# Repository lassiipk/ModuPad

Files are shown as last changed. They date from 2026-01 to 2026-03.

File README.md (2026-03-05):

# MODUPAD
| CAD | *IRL* |
|---|-----|
| ModuPad_FullProduct_Image |  |

**MODUPAD** is a compact **3×3 programmable macropad with a rotary encoder** designed with a **macro‑first, learning‑driven philosophy**.  

This project represents a **from‑scratch learning journey** covering electronics, schematic design, PCB layout, firmware architecture, and documentation—while still resulting in a practical, daily‑use device.

---
<!--
## Device Identity

> **MODUPAD** is a **3×3 macropad + rotary encoder** with layered keymaps, encoder‑driven system control, and an event‑based OLED interface.

---

## Project Goals

- Learn electronics **from near zero** through hands‑on design
- Design a complete keyboard matrix with diodes
- Integrate a microcontroller, rotary encoder, and OLED display
- Build a full PCB in KiCad (schematic → layout → DRC‑clean)
- Design firmware architecture before hardware arrival
- Practice clean documentation and GitHub‑based version control
- Produce a focused, usable macropad without feature creep

This project prioritizes **learning clarity, reasoning, and correctness** over visual complexity.
-->

<!--
## Final Key Features (As Built)

- **3×3 key matrix (9 keys)** dedicated entirely to macros
- **Multiple firmware layers**
  - Layer 0 (Default)
  - Layer 1 (Fn layer)
  - Layer 2 (planned / future)
- **EC11 rotary encoder**
  - Rotation: system volume control
  - Button: OLED mode control
- **0.91” 128×32 I²C OLED**
  - Animation mode
  - Text mode
  - Status mode
  - Full OFF state
- **USB‑C connectivity**
- **Windows‑focused macro design** (Windows 10 & 11)
- **No RGB lighting** (removed during redesign to reduce complexity)

---
<!--
## Encoder Behavior

### Encoder Rotation
- Controls **system volume only**
- Small step size for precision
- Works across **Windows 10 & 11**

### Encoder Button
- **Press:** Cycle OLED animations
- **Fn + Press:** Cycle text/status modes
- **Fn + Hold (3s):** OLED ON / OFF toggle

---

## OLED System

### OLED Modes
1. **Animation Mode**
   - Plays one full animation per `animation_xx.py`
   - Firmware auto‑detects all animation files
   - No hard limit on number of animations
2. **Text Mode**
   - Displays:
     - Creator name
     - Date & time
3. **Status Mode**
   - Displays system states (e.g. mute status)
4. **OFF Mode**
   - OLED fully powered down (true blank state)

OLED behavior is **event‑driven**, not continuously animated.

---

 ## Development Status (Current)

- [x] Concept defined
- [x] Schematic completed
- [x] PCB layout completed
- [x] DRC‑clean board
- [x] Case designed
- [x] Firmware architecture finalized
- [x] Firmware written
- [x] Project uploaded to GitHub
- [ ] Hardware fabrication & assembly
- [ ] Flashing & physical testing
-->

## Firmware Overview

- **Firmware Framework:** KMK (Python‑based)

---

<!-- **Reason for KMK**
  - Python readability
  - Clear firmware structure
  - No dependency on VIA
  - Easier reasoning without hardware in hand

Firmware was designed **before physical assembly**, allowing logic review and iteration in advance.

---

## Why MODUPAD?

**MODUPAD** stands for:
- **MODU** — Modular, adaptable, intentional
- **PAD** — A focused input device

Every decision made in this project supports **clarity, control, and learning**.

---

-->

## Bill of Materials (BOM):
- **Microcontroller:** Seeed Studio XIAO RP2040
- **Keys:** 9 × MX‑style switches
- **Diodes:** 10 1N4148 Diodes (matrix isolation)
- **Encoder:** EC11 rotary encoder with push button
- **Display:** 0.91” I²C OLED (128×32)
- **Connectivity:** USB‑C
- **Case:** Custom‑designed in Fusion 360, 3D‑printed

---

| Schematic | PCB | Case |
|---|-----|---|
| KiCad Schematic | KiCad PCB | Case Screenshot |

---

### Timeline

**Project Started:** 19th December, 2025 | 11:58 PM

**Project Ended:** 2nd January, 2026 | 7:58 PM

**Project Submited:** 2nd January, 2026 | 11:17 PM

**Project 99% Completed:** 12 Febuary | 1:00 PM

**Project 100% Completed:** N/a

---

## License

This project is open‑source and intended for **educational and personal use**.

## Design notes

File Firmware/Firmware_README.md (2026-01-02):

# ModuPad – Firmware Documentation

**Author:** M. Saim Ghazanfar  
**Project:** ModuPad  
**Scope:** Firmware only (KMK-based)

---

## Overview

This document describes the **final firmware design** for the ModuPad project.  
Everything written here is based **strictly on real discussion, iteration, approvals, and decisions** made during the ModuPad firmware design process.

No assumptions.  
No features added afterward.  
No undocumented behavior.

This README is intended for:
- GitHub documentation
- Hack Club project submission
- Future maintenance and expansion
- Learning & documentation purpose

---

## Firmware Goals (Initial Plan)

The original firmware goals were:

- Use **KMK Firmware** (Python-based)
- Avoid VIA to keep things simple and controlled
- Support:
  - 3×3 macro keypad
  - Rotary encoder (rotation + button)
  - OLED display (128×32)
- Work on **Windows 10 and Windows 11**
- Be usable and testable **even before hardware arrives**
- Keep macros **OS-level and reliable**

---

## Key Design Changes & Decisions

### Removed Features
- Addressable LEDs  
  **Reason:**  
  - Took too much PCB space  
  - Increased schematic and firmware complexity  
  - Interfered with encoder placement  

### Changed Approach
- **Discord-specific mute removed**  
  Replaced with **Global Mic Mute**, which works system-wide.

- **Key-combo-heavy macros reduced**  
  Replaced with **Windows `.bat` scripts** for:
  - Stability
  - OS-wide behavior
  - Easy customization without firmware edits

---

## Firmware Stack

- **Firmware:** KMK (Python)
- **Architecture Style:** Modular
- **OS Target:** Windows 10 & Windows 11
- **OLED Resolution:** 128×32
- **Encoder:** Single EC11-style rotary encoder

---

## OLED Animation System

### Animation Files
- Each `animation_xx.py` file represents:
  - **One complete animation**
  - **Not individual frames**
> Example:
>
> OLED_ANIMATIONS/  
> ├── animation_01.py  
> ├── animation_02.py  
> ├── animation_03.py  
> └── animation_04.py

---

### Behavior
- Firmware automatically:
- Detects all animation files
- Loads them dynamically
- Cycles through them using the encoder button
- **No hard limit** on number of animations
- Users can:
- Add or remove animation files
- Without changing firmware logic

---

## Encoder Behavior (Final)

### Rotation
- Controls **system volume only**
- Small step size:
- **2 volume steps per tick**
- Works on:
- Windows 10
- Windows 11

### Encoder Button
| Action | Result |
|---|---|
| Press | Switch OLED animation |
| Fn + Press | Switch OLED text / status mode |
| Fn + Hold (3 seconds) | OLED OFF / ON toggle |

- OLED OFF state is **fully blank**
- No dimming or partial display

---

## Key Layout & Functions

### Physical Layout
- **3×3 matrix**
- Numbered **bottom-left → top-right**

> 7 8 9
>
> 4 5 6
>
> 1 2 3

---

### Layer 0 – Default

| Key | Function |
|---|---|
| 1 | Fn (momentary layer switch) |
| 2 | Screenshot (Win + Fn + Print) |
| 3 | Redo (Ctrl + Shift + Z) |
| 4 | Copy (Ctrl + C) |
| 5 | Paste (Ctrl + V) |
| 6 | Undo (Ctrl + Z) |
| 7 | Open Photoshop (`App1.exe`) |
| 8 | Open Browser |
| 9 | Open File Explorer |

---

### Layer 1 – Fn Held

| Key | Function |
|---|---|
| 1 | --- |
| 2 | Global Mic Mute / Unmute |
| 3 | Window Switch (Alt + Tab) |
| 4 | Task Manager (Ctrl + Shift + Esc) |
| 5 | Toggle Speaker Mute |
| 6 | Open Game (`Game.exe`) |
| 7 | Windows Sleep |
| 8 | Windows Restart |
| 9 | Windows Shutdown |

---

### Key Layout & Functions — Layer 2 (Future Planned Feature)

> **Status:** Planning stage only  
> **Not implemented in current firmware**

### Layer Activation Logic (Proposed)
- **Trigger:** Press the **Fn key 5 times consecutively** (within a short time window).
- **Result:** Activates **Layer 2** (third layer, after Layer 0 and Layer 1).
- **Exit:** Press the **Fn key 5 times consecutively again** to return to **Layer 0 (Default)**.
- This design avoids adding extra physical keys and keeps the hardware simple.

### Intended Purpose of Layer 2
- Reserved for **advanced / power-user macros**.
- Experimental features without disturbing daily-use layers.
- Future expansion space for:
  - App-specific macro sets
  - Debug / development shortcuts
  - OLED debug or diagnostic modes
  - User-customizable workflows

### Design Notes
- Layer 2 is **deliberately not finalized**.
- Key assignments will be defined only after real-world usage of Layer 0 and Layer 1.
- Firmware architecture is designed to allow adding this layer **without breaking existing behavior**.

### Rationale
- Prevents accidental activation.
- Keeps Layer 0 and Layer 1 clean and predictable.
- Provides long-term scalability for ModuPad without hardware redesign.

---

## Windows `.bat` Script Philosophy

### Why `.bat` Files?
- More reliable than key combos
- Work regardless of focused application
- OS-wide behavior
- Easy to edit or replace

### Folder Structure Used by Firmware

> ModuPad/
> ├── Apps_Macros/
> │   ├── App1.exe
> │   └── Game.exe
> │
> ├── Windows_BootOptions/
> │   ├── sleep.bat
> │   ├── restart.bat
> │   └── shutdown.bat
> │
> ├── Utilitits/
> │   ├── Volume_toggle.bat
> │   └── mic_toggle.bat
> │
> ├── OLED_ANIMATIONS/
> │   ├── animation_01.py
> │   ├── animation_02.py
> │   └── animation_03.py
> │
> └── README.md

- Users can replace `.exe` or `.bat` files without touching firmware.

---

## Firmware Architecture Summary

The firmware is written entirely in Python using KMK and is split conceptually into:

- Key matrix handling
- Encoder handling
- OLED manager
- Animation loader
- Macro execution system

The firmware is designed so that:
- It can be written and reviewed **without hardware**
- Behavior is deterministic
- Features are easy to extend later

---

## What Was Learned

- Simplifying early saves time later
- Hardware constraints should guide firmware decisions
- OS-level automation is more reliable than app-specific shortcuts
- OLED usability matters more than flashy visuals
- KMK is powerful even without VIA
- Clear documentation prevents future confusion

---

## Final Notes

This firmware is:

- Purpose-built
- Minimal
- Reliable
- Easy to expand
- Fully aligned with the ModuPad hardware

All firmware decisions documented here are based **entirely on real design discussion and iteration**, not assumptions.

---

**ModuPad Project – Firmware**  
**Author:** Muhammad Saim Ghazanfar

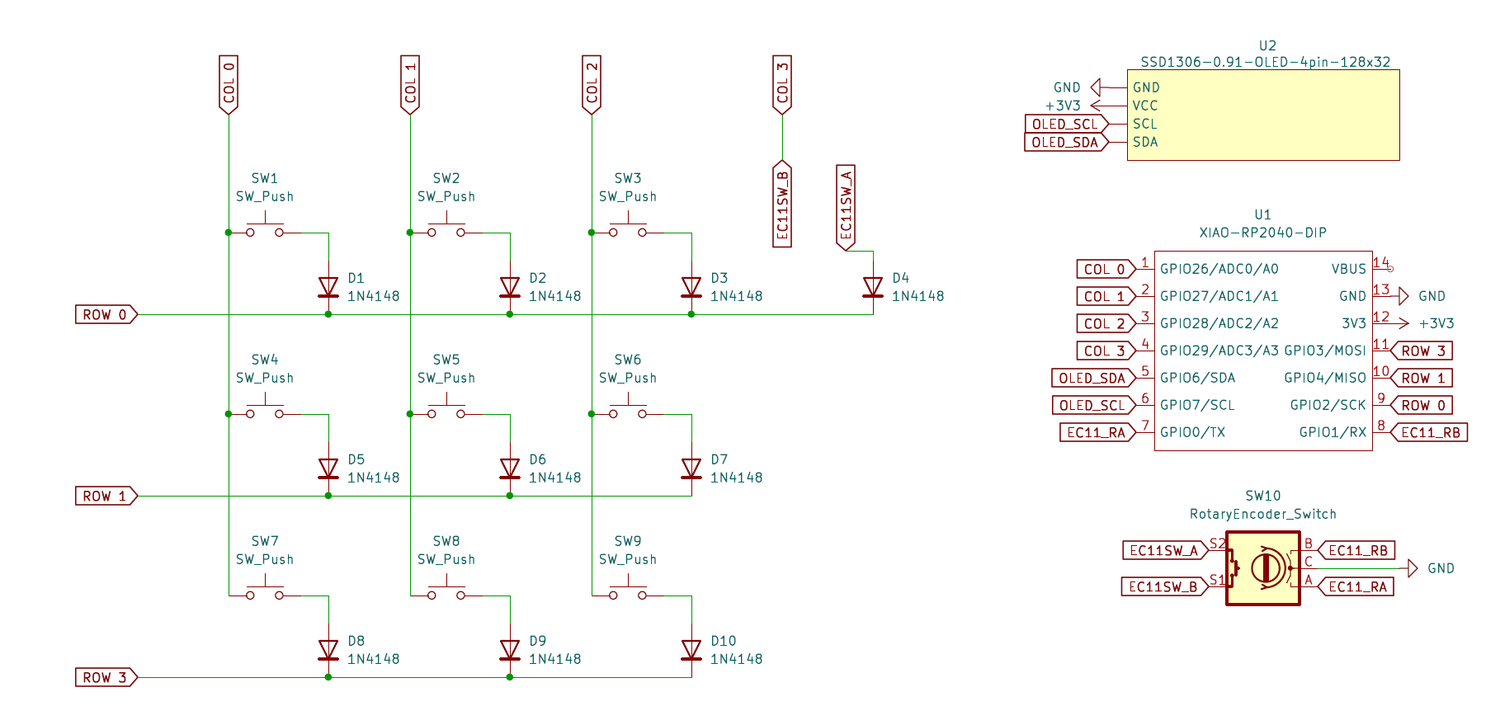
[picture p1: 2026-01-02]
Images/KiCad_Images/01_KiCad_Schematic.png

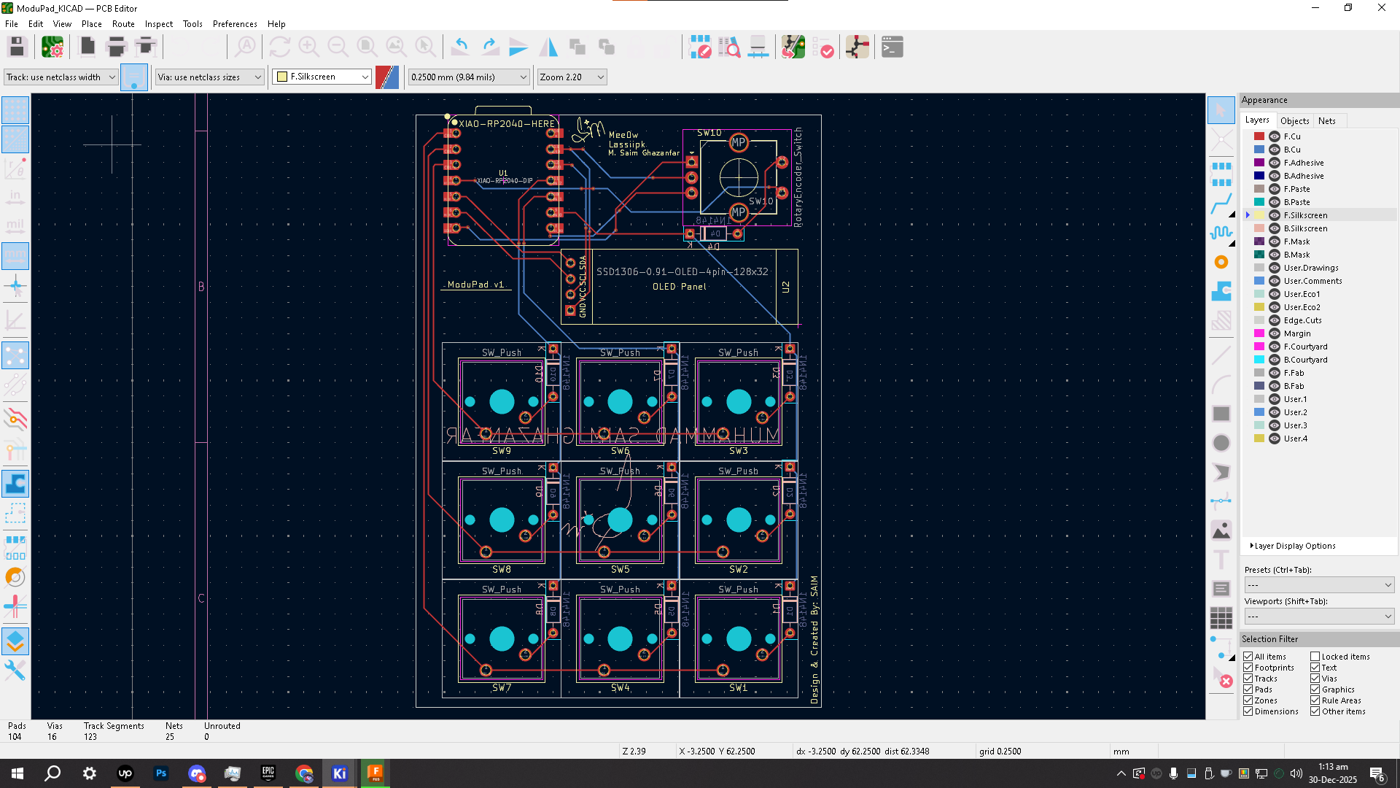
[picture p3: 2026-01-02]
Images/KiCad_Images/02_KiCad_PCB.png

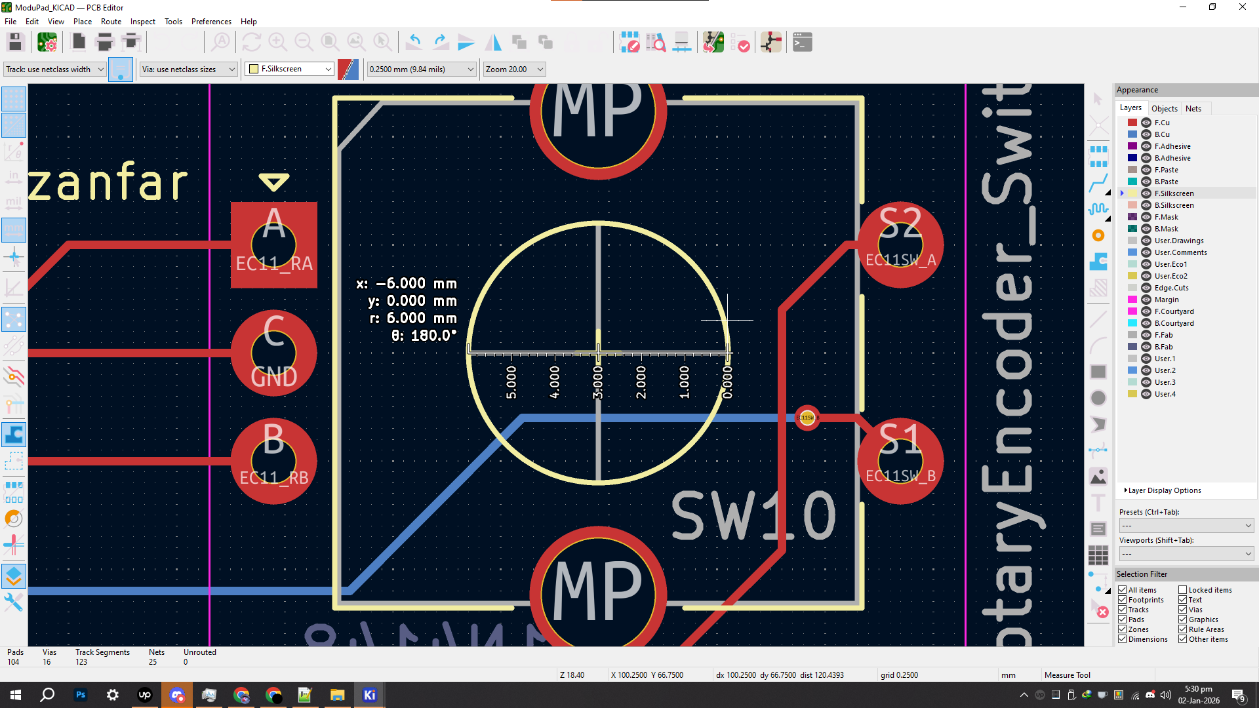
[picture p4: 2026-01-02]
Images/KiCad_Images/07_KiCad_EC11_Encoder-Diameter-Dimentions.png

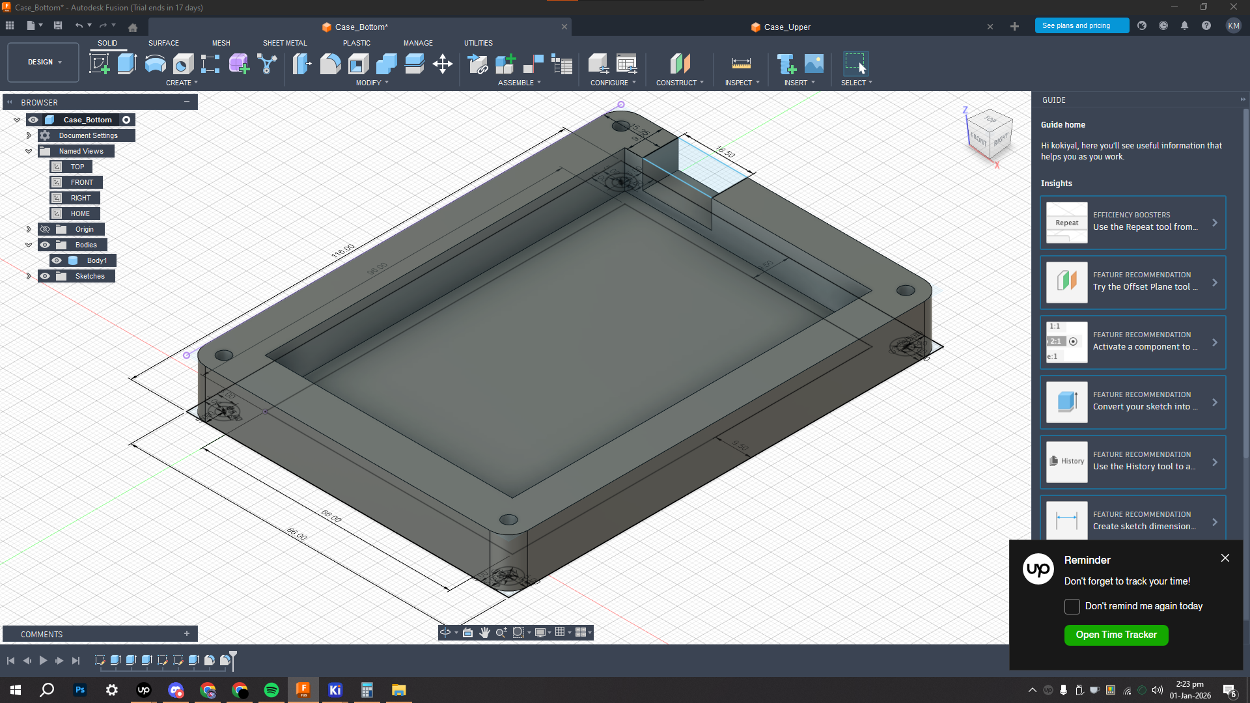
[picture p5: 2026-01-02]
Images/CAD_Images/03_ModuPad_BottomCase_ExtrudeDimentions.png

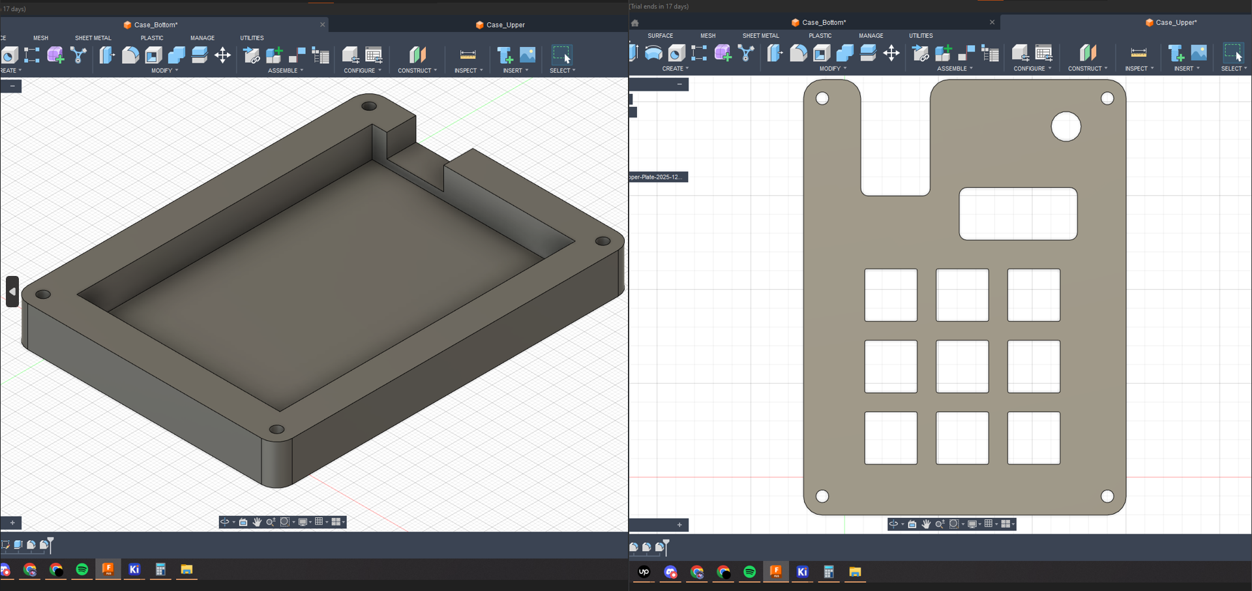
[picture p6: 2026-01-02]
Images/CAD_Images/Screenshot 2026-01-02 214436.png

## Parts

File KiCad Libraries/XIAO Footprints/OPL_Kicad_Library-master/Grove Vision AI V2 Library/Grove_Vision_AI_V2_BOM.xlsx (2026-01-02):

Layer Jump | Number | Name | Specification | Operating Temperature | MPN Code | Quantity | Base | Plug Position | Process
N | 301010000 | SMD RES 0R-5%-1/16W;0402 |  | -55°C to 155°C | RC0402JR-070RL | 3 | 1 | R29,R30,R39 | SMT1
N | 301010004 | SMD RES 10K-5%-1/16W;0402 |  | -55°C to 155°C | RC0402JR-0710KL | 7 | 1 | R5,R7,R8,R23,R24,R31,R38 | SMT1
N | 301010008 | SMD RES 510K-5%-1/16W;0402 |  | -55°C to 155°C | RC0402JR-07510KL | 1 | 1 | R35 | SMT1
N | 301010456 | SMD RES 100K-1%-1/16W;0402 |  | -55°C to 155°C | RC0402FR-07100KL | 7 | 1 | R6,R10,R11,R16,R32,R33,R37 | SMT1
N | 301010495 | SMD RES;5.1K-1%-1/16W;0402 |  | -55°C to 155°C | RC0402FR-075K1L | 3 | 1 | R2,R3,R36 | SMT1
N | 301010746 | SMD RES 2.2K-1%-1/16W;0402 |  | -55°C to 155°C | RC0402FR-072K2L | 10 | 1 | R1,R4,R13,R14,R15,R19,R20,R21,R22,R40 | SMT1
N | 301011331 | SMD RES 22.1K-1%-1/16W;0402 |  | -55°C to 155°C | RC0402FR-0722K1L | 2 | 1 | R26,R34 | SMT1
N | 302010004 | SMD CAP Ceramic 100nF-16V-10%-X7R;0402 |  | -55°C to 125°C | CC0402KRX7R7BB104 | 18 | 1 | C5,C8,C13,C20,C21,C22,C23,C24,C25,C26,C27,C29,C30,C31,C32,C35,C36,C39 | SMT1
N | 302010006 | SMD CAP Ceramic 10nF-50V-10%-X7R;0402 |  | -55°C to 125°C | CC0402KRX7R9BB103 | 1 | 1 | C3 | SMT1
N | 302010049 | SMD CAP Ceramic 12pF-50V-5%-NPO;0402 |  | -55°C to 125°C | CC0402JRNPO9BN120 | 2 | 1 | C14,C15 | SMT1
N | 302010051 | SMD CAP Ceramic 220nF-16V-10%-X7R;0402 |  | -55°C to 125°C | CC0402KRX7R7BB224 | 1 | 1 | C16 | SMT1
N | 302010407 | SMD CAP Ceramic 4.7uF-10V-10%-X5R;0402 |  | -55°C to 85°C | CC0402KRX5R6BB475 | 7 | 1 | C4,C6,C7,C9,C10,C28,C34 | SMT1
N | 302010519 | SMD CAP Ceramic 10uF-10V-20%-X5R;0402 |  | -55°C to 85°C | CC0402MRX5R6BB106 | 2 | 1 | C11,C37 | SMT1
N | 302013249 | SMD CAP Ceramic 1uF-10V-10%-X5R;0402 |  | -55°C to 85°C | CL05A105KP5NNNC | 5 | 1 | C1,C2,C17,C18,C19 | SMT1
N | 303010544 | SMD Inductor 4.7uH-20%-1.1A;0806 |  | -40°C to 105°C | VLS201610HBX-4R7M-1 | 1 | 1 | L1 | SMT1
N | 303011858 | SMD Inductor 470nH-20%-2.6A;0603 |  | -40°C to 125°C | TFM160808ALC-R47MTAA | 2 | 1 | L2,L3 | SMT1
N | 304011053 | SMD Diode Schottky 40V-1A;SOD-323 |  |  | B5819WS SL | 4 | 1 | D1,D2,D3,D4 | SMT1
N | 304090121 | SMD LED Clear-Green;0402 | As posted |  | BL-HGE37A-AV-TRB | 1 | 1 | LED2 | SMT1
N | 304090746 | SMD LED Clear-Yellow;0402 | As posted |  | 16-213/Y2C-AN2Q1B/3T | 1 | 1 | LED1 | SMT1
N | 305030071 | SMD MOSFET N-CH 20V-500mA;SOT-523 |  |  | CJ1012 | 5 | 1 | Q1,Q2,Q3,Q4,Q5 | SMT1
N | 306011444 | SMD Crystal;24MHz-12pF-10ppm-4P-2.0*1.6*0.5mm |  | -40°C to 85°C | Y2400FE001 | 1 | 1 | X1 | SMT1
N | 310011697 | SMD IC MCU;Dual Cortex-M55 Core(Max 400MHz)-With a 400MHz NPU;WLCSP-65 | L5.58*W2.27mm | -40°C to 85°C | HX6538-A01TWA | 1 | 1 | U1 | SMT1
N | 310032794 | SMD IC PMIC;DCDC Buck-ADJ-2.2MHz-4A;DFN1.5×1.5-6 |  | -40°C to 85°C | SY80004DQD | 2 | 1 | U4,U6 | SMT1
N | 310032813 | SMD IC PMIC;LDO-1.8V-300mA;XTDFN-1*1-4L |  | -40°C to 125°C | SGM2036S-1.8XXDH4G/TR | 1 | 1 | U3 | SMT1
N | 310071431 | SMD IC Interface USB to High Speed TTL;QFN16 | USB to High-Speed Serial Port | -40°C to 85°C | CH343P | 1 | 1 | U2 | SMT1
N | 310091468 | SMD IC Memory;128Mbit-1.8V;SOIC-8 |  | -40°C to 85°C | W25Q128JWSIQ | 1 | 1 | U5 | SMT1
N | 311020009 | SMD Top Button 4N;4P-L4.6*W3.2*H2.5mm |  | -20°C to 70°C | SKRPADE010 | 1 | 1 | RST1 | SMT1
N | 311020518 | SMD Top Button 1.57N;4P-L4.6*W3.2*H2.5mm |  | -30°C to 85°C | SKRPABE010 | 1 | 1 | BOOT1 | SMT1
N | 312030502 | SMD DIGITAL MIC OMNI -26dBFS;OCLGA-4:3.5*2.65*0.94mm |  | -40˚C to 100˚C | MSM261D3526H1CPM | 1 | 1 | MIC1 | SMT1
N | 319015667 | PCB;Grove - Vision AI Module V2 -蓝油白字-4层 | 20*40*1.6mm-ENIG-FR4;Steel mesh code；404012305 |  |  | 1 | 1 |  | SMT1
N | 320011358 | SMD USB TYPE C-W/P;12+4P-8.94*7.35*3.26mm |  | -30°C to 85°C | USB-31C-F-16P-L7.35 | 1 | 1 | J1 | SMT1
N | 320031231 | DIP Black Female Header VERT;1*7P-2.54-5.0mm |  | -40℃ to 105℃ |  | 2 | 1 | P8,P9 | Unit
N | 320060904 | SMD FPC CONN Bottom Contact;15P-1.0mm;L19.9*W6.76*H2.0mm |  | -30°C to 85°C | ST-FPC-W102015-D | 1 | 1 | J2 | SMT1
N | 320090535 | SMD uSD Card Holder;9+4P-L11.25*W6.96*H1.42mm |  | -25°C to 70°C | ST-TF-MR267 | 1 | 1 | J5 | SMT1
N | 320110032 | SMD Grove Female Header-Beige;4P-2.0-90D | 2.0-4PHorizontal Mount with Locking Socket |  | PHS-4A horizontal mount | 1 | 1 | J3 | SMT1

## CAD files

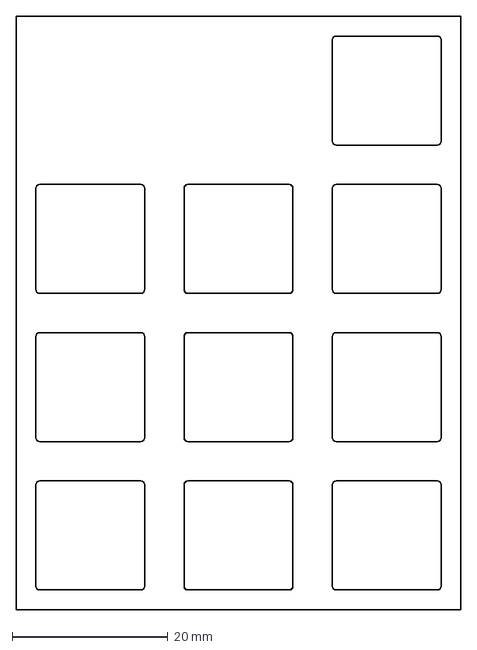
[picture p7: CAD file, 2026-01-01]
CAD/DXF_Files/ModuPad_Upper-Plate-2025-12-28T20_50_54.815Z.dxf
57.1 x 76.2 mm

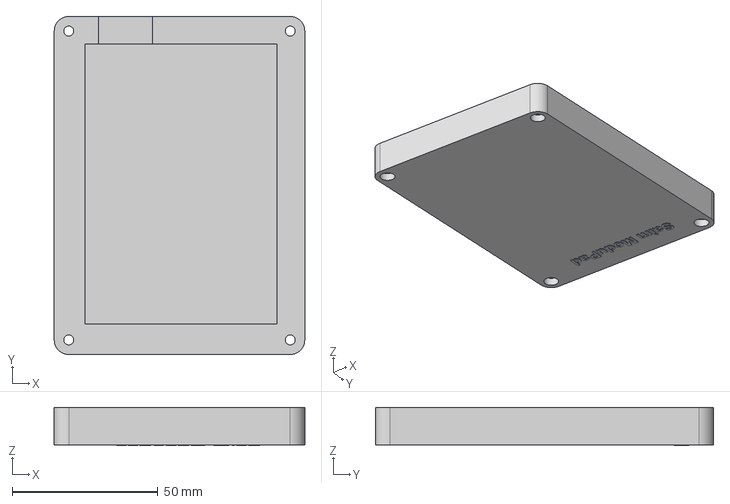
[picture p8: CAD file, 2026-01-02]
CAD/STEP_Files/Case_Bottom.step
86.0 x 116.0 x 13.2 mm

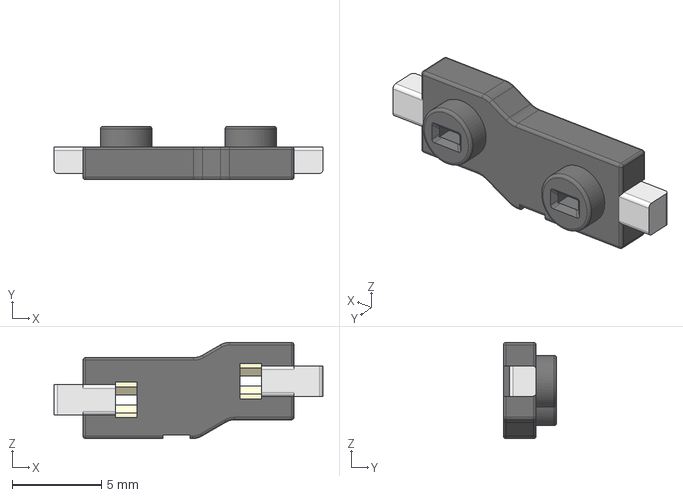
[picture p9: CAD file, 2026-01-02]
KiCad Libraries/Keyswitch_Footprints/MX_V2-main/3D/Gateron-KS33-Socket.step
15.1 x 3.00 x 5.40 mm

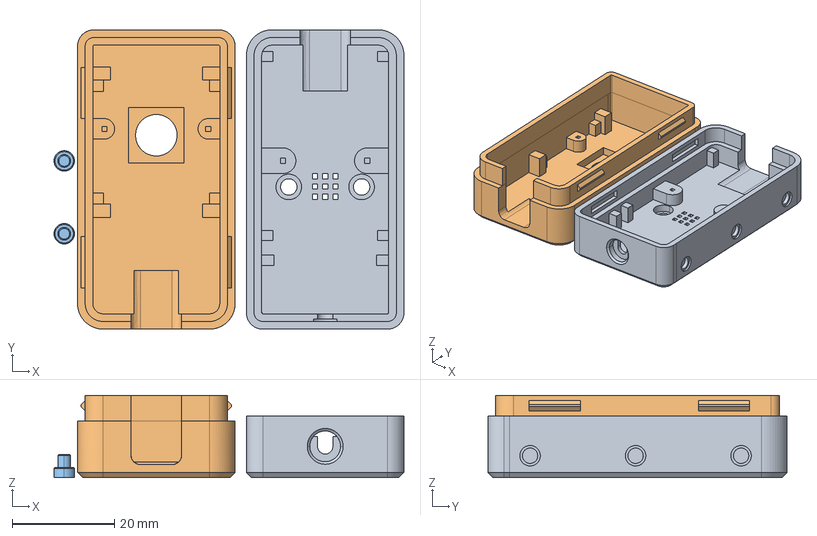
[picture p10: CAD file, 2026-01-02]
KiCad Libraries/XIAO Footprints/OPL_Kicad_Library-master/Grove Vision AI V2 Library/himax.stp
68.4 x 58.5 x 16.1 mm

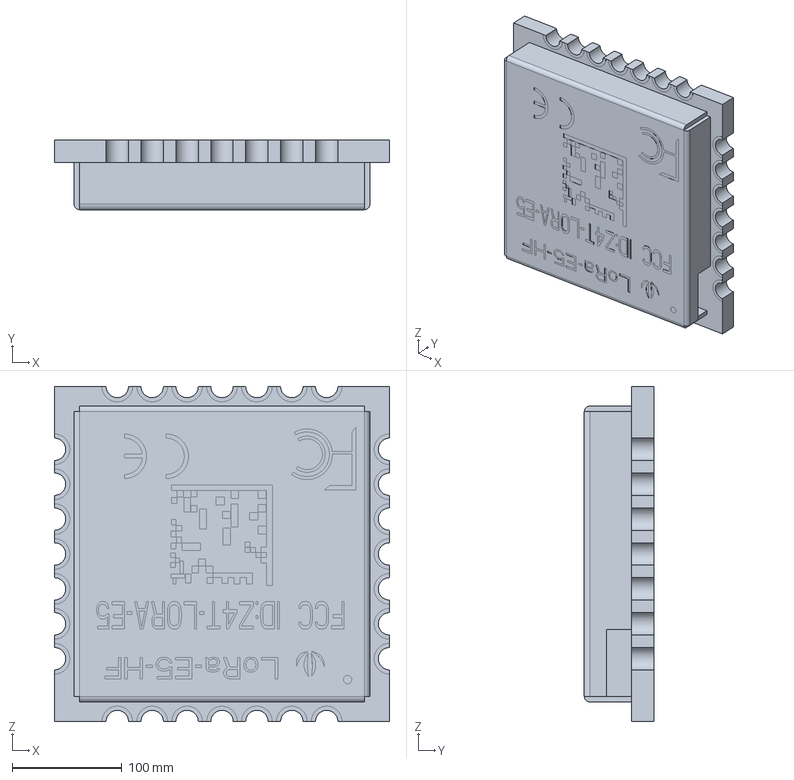
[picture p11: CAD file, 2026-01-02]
KiCad Libraries/XIAO Footprints/OPL_Kicad_Library-master/Seeed Studio Wio Series/Wio-E5-LE/LoRa-E5-LE-HF_3D_File.stp
304.8 x 63.8 x 304.8 mm

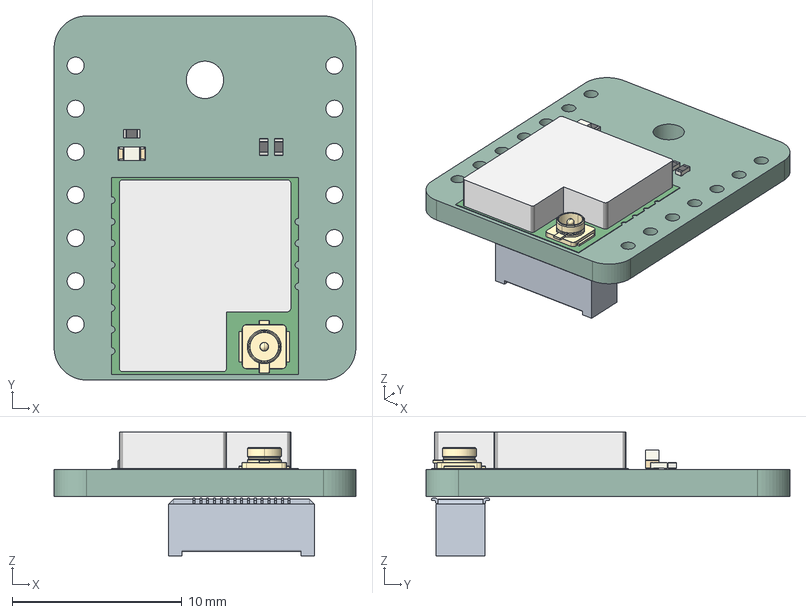
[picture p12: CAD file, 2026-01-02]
KiCad Libraries/XIAO Footprints/OPL_Kicad_Library-master/Seeed Studio Wio Series/Wio-SX1262/Wio-SX1262_for_XIAO_3D_file.step
17.8 x 21.4 x 7.30 mm
R_0402_1005Metric x 3
LED_0603_1608Metric
PCB
BF04-30pin-35H
Wio-SX1262 for XIAO V1.0_PCB

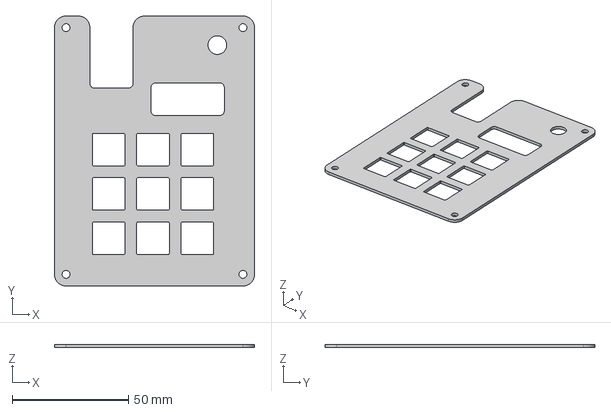
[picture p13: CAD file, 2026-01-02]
CAD/STEP_Files/Case_Upper.step
86.0 x 116.0 x 1.50 mm

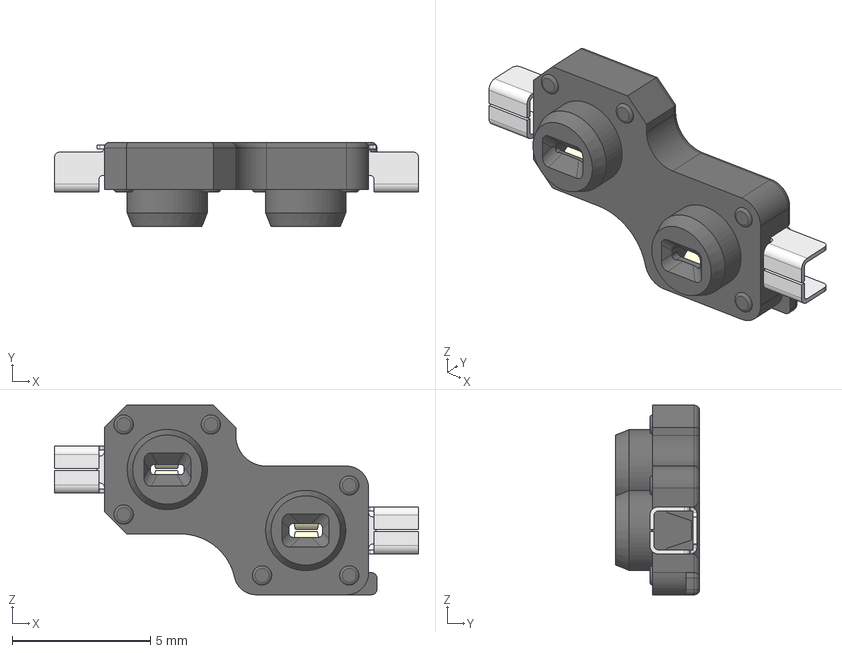
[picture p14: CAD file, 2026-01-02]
KiCad Libraries/Keyswitch_Footprints/MX_V2-main/3D/Kailh-Choc-Socket-CPG135001S30.step
13.1 x 3.05 x 6.85 mm
Insert 2
Insert 1

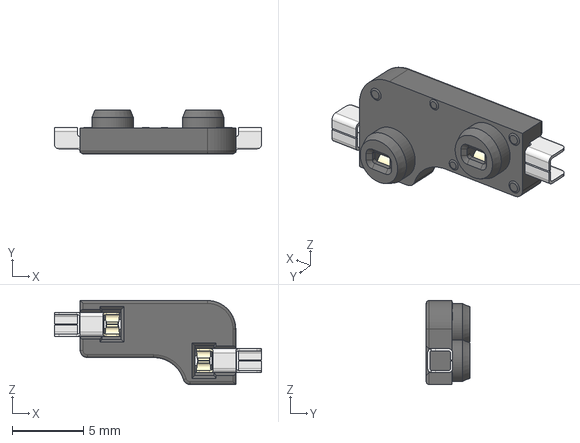
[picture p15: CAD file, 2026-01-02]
KiCad Libraries/Keyswitch_Footprints/MX_V2-main/3D/MX-Hotswap-Socket.step
14.5 x 3.05 x 5.89 mm

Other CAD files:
CAD/F3D_Files/Case_Bottom.f3d
CAD/F3D_Files/Case_Upper.f3d
CAD/STL_Files/Case_Bottom.stl
CAD/STL_Files/Case_Upper.stl
KiCad Libraries/XIAO Footprints/OPL_Kicad_Library-master/Grove Vision AI V2 Library/himax.3mf

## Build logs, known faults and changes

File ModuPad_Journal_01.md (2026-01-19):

## Update

### 🔧 Soldering Iron
I ordered the soldering iron through my **18$ Grant** on **5 January 2026**.  
It was delivered on **17 January 2026** and received by me on **19 January 2026**.  
Total time in transit was **14 days**.

### 🧩 PCB & Components
The **PCB order has been placed** and is currently on its way.  
I also received an **email confirmation** stating that all required pad components have been shipped.

### 🖨️ 3D-Printed Case
The 3D-printed case was delayed due to issues with the grant during the purchasing phase.  
These issues are now resolved, and **the print payment has been confirmed and completed**.  
The order is ready to proceed.

### ✅ Status
The project is now clear of purchasing issues, and I am excited to complete it as soon as the remaining parts arrive.

---

### 📸 Images
| Image 1 | Image 2 | Image 3 |
|---|---|---|
| IMG_20260119_162121_Censored |  |  |

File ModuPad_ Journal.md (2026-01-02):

# Creating a HackPad (Macropad) from Scratch  
**A Zero‑to‑One Electronics Learning Project**

---

## 1. Project Context

### Objective and Scope
This project documents the complete journey of designing and building a custom **HackPad (macropad)** from scratch, starting with near‑zero electronics and PCB design knowledge and progressing through schematic design, PCB layout, enclosure design, and firmware development.

The scope explicitly includes:
- Electronics learning through practice (schematic → PCB → firmware)
- Iterative redesigns and corrections
- Firmware architecture using KMK
- Reflection on learning efficiency and mistakes

Manufacturing and physical assembly are out of scope for this report.

### Initial Skill Level and Constraints
- Near‑zero prior experience in:
  - Electronics fundamentals
  - PCB design tools (KiCad)
  - Keyboard firmware
- Constraints:
  - No immediate access to hardware during firmware development
  - Learning occurred primarily through iterative problem‑solving and feedback
  - Public documentation intended for GitHub

### Motivation
- Learn electronics by building a real, functional device
- Replace theory‑only learning with applied design
- Create a personal reference for future projects

---

## 2. Planning Phase

### Explicit Plans
- Design a custom macropad with:
  - 3×3 key matrix
  - Rotary encoder
  - OLED display
  - Custom firmware
- Use KiCad for schematic and PCB
- Use KMK firmware (Python‑based)

### Implicit Assumptions
- Editing symbols and footprints would be straightforward
- Firmware complexity would be manageable late in the project
- Features could be added incrementally without architectural impact

### Missing or Flawed Planning
- Underestimated:
  - Footprint management complexity
  - ERC/DRC iteration time
  - Firmware architecture planning
- No early firmware‑hardware co‑design planning

---

## 3. Execution & Accomplishments

### Completed
- Fully wired schematic with zero ERC errors
- PCB layout with resolved DRC issues
- Case design in Fusion 360
- Complete firmware architecture and keymap
- Project uploaded to GitHub

### Assumed but Initially Incomplete
- Correct footprint libraries
- Encoder/OLED integration logic
- Clean firmware structure

### Partial Progress Areas
- Advanced firmware layers (future‑planned, not implemented)
- Hardware validation pending part delivery

---

## 4. Redesigns, Revisions, and Direction Changes

### Major Changes
- Removal of LEDs due to space and complexity
- Redesign of key matrix and encoder placement
- Shift from application‑specific shortcuts to OS‑level scripts
- Separation of mic mute and volume mute logic

### Why Changes Occurred
- Physical constraints
- Firmware reliability concerns
- Over‑engineering early features

### Impact
- Simplified hardware
- More reliable firmware
- Improved learning clarity

---

## 5. Hard Parts & Friction Points

### Technical
- KiCad symbol vs footprint mismatches
- ERC and DRC error interpretation
- OLED pin duplication issues
- Encoder footprint mismatches

### Cognitive
- Overconfidence in early decisions
- Difficulty forming correct mental models
- Feature creep before core stability

### Communication
- Misinterpretation of feature intent (e.g., audio output vs mute)

---

## 6. Timeline, Progress Tracking & Traceability

- All timestamps originate from chat messages
- Timezone reference: **Pakistan Standard Time (Islamabad)**

### Limitations
- Some early conceptual shifts span multiple messages
- No explicit “milestone completion” timestamps were recorded
- Gaps exist between understanding → decision → action

These gaps are explicitly acknowledged as a learning limitation.

---

## 7. Learning Analysis

### Explicit Lessons
- Firmware must follow hardware reality
- Simpler designs accelerate learning
- ERC/DRC are learning tools, not obstacles

### Implicit Learning
- Importance of iteration
- Value of removing features
- Documentation clarifies thinking

### Missed Opportunities
- Earlier firmware prototyping
- Earlier external reference checking

---

## 8. Learning Mapped to Electronics Fundamentals

- **MCU Basics:** GPIO mapping, power pins, VBUS handling
- **Switch Matrices:** Rows, columns, diodes, ghosting prevention
- **Power:** 3.3 V rails, grounding discipline
- **Firmware:** Matrix scanning, layers, event handling

---

## 9. Mistake Classification

### Knowledge Gaps
- Footprint libraries
- OLED module variations

### Execution Errors
- Missing footprints
- Misassigned nets

### Reasoning Failures
- Assuming shortcuts equal robustness
- Adding features before stabilizing architecture

---

## 10. Confidence vs Actual Understanding

- **Overconfidence:** Early schematic confidence before ERC mastery
- **Underconfidence:** Firmware hesitation despite adequate Python skill
- Impact: Rework and delays

---

## 11. Assumptions, Errors, and Reasoning Failures

- Assuming editing symbols was unavoidable
- Assuming app‑specific shortcuts were reliable
- Underestimating firmware architecture importance

---

## 12. External Research Gaps

- Limited early reading on keyboard firmware structure
- Minimal upfront review of OLED integration examples

Consequences:
- Relearning concepts mid‑project

---

## 13. Cause–Effect Evaluation

### Accelerators
- Removing LEDs
- Switching to OS‑level scripts
- Clear feature approval checkpoints

### Slowdowns
- Feature creep
- Late architecture decisions

---

## 14. Next Steps After Learning

- Hardware assembly and testing
- Firmware refinement based on real‑world use
- Power and EMI considerations

---

## 15. Concept Glossary

- **ERC:** Electrical Rules Check
- **DRC:** Design Rules Check
- **KMK:** Python‑based keyboard firmware
- **Matrix Scanning:** Reading keys via rows and columns
- **Footprint:** Physical PCB representation of a component

---

## 16. Future Prompt Generation

- “Explain matrix scanning at the electrical level”
- “Compare KMK vs QMK architecture”
- “Best practices for small OLED firmware design”

---

## 17. Improvement Recommendations

- Plan firmware earlier
- Freeze hardware before feature expansion
- Document assumptions explicitly

---

## 18. Post‑Completion Review

In hindsight:
- Feature reduction improved learning
- Documentation should start earlier
- Architecture decisions matter more than polish

---

## 19. Improved Version Proposal (v2)

### Hardware
- More keys
- Dedicated power filtering
- Optional expansion headers

### Firmware
- Multi‑layer state machine
- Configurable animation loader
- Optional host communication

### Learning Process
- Research → design → implement → reflect loop
- Earlier validation checkpoints

---

**Status:**  
Project completed up to firmware stage.  
Repository publicly available.  
This document reflects real decisions, real mistakes, and real learning—without fabrication.

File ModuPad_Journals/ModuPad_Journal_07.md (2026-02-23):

**9 Feb 2026**

After the previous day’s failures, I shifted my focus to testing the key switches since the encoder functionality was still not behaving as intended.

After a lot of struggle, I finally managed to make one key respond as an input device — just like a normal keyboard key. I had to experiment with pin assignments to figure out the correct configuration, but I eventually got it working.

Then I managed to get three keys in a column working simultaneously.

My encoder button was part of the matrix, so I got that working too.

However, no matter what I tried, only four keys were functioning. The rest were completely unresponsive. I couldn’t figure out why.

---

> Journal Entry Written: 11 Feb 2026 | 12:50 - AM

---



---

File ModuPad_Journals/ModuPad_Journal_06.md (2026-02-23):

### ModuPad – CASE

---

### Images
| Image 1 | Image 2 | Image 3 |
|---|---|---|
| IMG_20260208_181629_Censored |  | IMG_20260208_181614_Censored |

---

My pad case was delivered on 8th Feb. The print quality was top-notch. I even complimented the person who printed it — the craftsmanship was impressive.

But there was bad news.

There were measurement errors and branding alignment issues. The encoder and display cutouts were slightly off relative to the PCB. The key switches and MCU placements were accurate, but the encoder and display alignment were wrong.

My father and I analyzed the issue and concluded that we needed to manually cut part of the upper plate to allow the encoder and display to fit correctly. The bottom case had no issues — the PCB fit perfectly there.

We also realized something critical: we had to desolder the key switches. The correct assembly order required placing the upper plate first and then soldering the switches through it.

So we unsoldered the switches, modified (cut) the upper plate to properly align with the PCB, then reassembled everything and tightened the screws.

Honestly, it looked great after the modification. Really satisfying to see it come together.

---

> Journal Entry Written: 11 Feb 2026 | 12:50 - AM

---

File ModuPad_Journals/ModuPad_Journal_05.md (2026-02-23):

**8 Feb 2026**

I continued testing the encoder to confirm everything was stable. After that, I moved on to implementing its intended function — controlling Windows volume.

I tried very hard but was unsuccessful.

After multiple failures, I shifted my focus to QMK-based firmware. Again, I faced difficulties. It was written in C, and everything felt very complicated. The reason I originally chose KMK over QMK was exactly this — QMK is very advanced and powerful, probably best suited for my ModuPad, but KMK is Python-based and easier to understand.

One big advantage of KMK was flashing. First, I installed CircuitPython onto the MCU. After that, the board appeared as a USB drive (CIRCUITPY / Seeed-XIAO-RP2040). Making changes was simple — I only had to modify `code.py` directly on the drive.

Despite that convenience, I struggled a lot with functionality. After many failed attempts, I quit for the day and went to sleep.

---

> Journal Entry Written: 11 Feb 2026 | 12:50 - AM

---

> The Image provided is of Compiling statusof  my OMK based Firmware.
>
> Ignore the mess around my Desk and LCD, its always like this!

733baa89-5d99-4c6c-8100-c8d66cede92e

---

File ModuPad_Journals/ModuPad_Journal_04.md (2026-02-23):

### Re-Writing Firmware

**7 Feb 2026**

After discovering that the firmware was not working for my Seeed XIAO RP2040, I had to dig deep into KMK firmware writing. I decided to create a simple test program to verify whether my pad was functioning properly — checking for wiring errors and confirming that everything was working as planned.

I managed to test my encoder by reading TRUE/FALSE signals that changed based on its rotation direction. That made it clear that the encoder hardware was working fine and should perform correctly in KMK.

No hardware issues.

---

> Journal Entry Written: 11 Feb 2026 | 12:50 - AM

---



---

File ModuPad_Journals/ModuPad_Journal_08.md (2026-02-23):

**9 Feb 2026 | 11:00 PM – 11:20 PM**

With an exhausted mind, I shifted my focus again — this time to the OLED screen.

I didn’t even know if it worked. Was there an electrical issue? A wiring mistake? Something else I overlooked?

It was confusing and frustrating. I felt like I wasn’t making progress.

Then I remembered that I had previously seen other HackPads in Hack Club repositories. I went back and searched through those projects. I found example code related to OLED displays and modified it to match my project.

It still didn’t work.

I used ChatGPT to debug the error, and I discovered the actual problem: I didn’t have the required libraries inside my CircuitPython `lib` folder.

After adding the correct libraries, the OLED finally worked.

It was extremely satisfying to see text displayed on the screen for the first time.

I experimented a bit more with the code and managed to display some cool custom text.

That moment felt like real progress.

Screenshot (510)

---

> Journal Entry Written: 11 Feb 2026 | 12:50 - AM

---

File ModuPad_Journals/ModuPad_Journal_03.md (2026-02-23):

### Components!

Receiving the components was a great experience — completely different from the PCB situation. They delivered everything right to my doorstep, which made it even better. I was genuinely excited. I wanted to solder them immediately.

When I opened the package, I was impressed. All the parts were very small, but very satisfying to look at and place on the PCB. Aligning them felt precise and accurate — they fit perfectly.

---

**Parcel received:** 5th Feb | 3:00 PM

After receiving it, I carefully examined all the parts. I checked everything thoroughly. I was tempted to start soldering right away, but I stopped myself because I needed to prepare properly before soldering onto the board.

At 11:00 PM, I finally started the soldering process.

Before soldering, I inspected everything again. Since I was about to solder all the components, I didn’t want to make a mistake. I first checked their placement on the PCB and only then began soldering.

I started with the MCU. It was very difficult. It was my first time soldering something that small, and the MCU pins were tiny. It was frustrating and honestly made me want to quit.

After struggling for quite a while, I managed to solder a single pin along with the header. The solder joint wasn’t perfect, but it was enough to keep the MCU from falling off.

Then I moved to the display — same situation. Then the key switches — same again. Then the encoder — again, same story. The solder joints were messy and not clean. Nothing looked professional.

By 1:00 AM, I was extremely frustrated and exhausted. I stopped soldering and went to sleep.

---

The next morning, my father checked my work. He knows how to solder, and he immediately told me my soldering wasn’t good enough. He then helped me redo everything properly and cleanly.

Getting help from him was a great experience. I learned a lot just by watching and assisting. Honestly, I don’t even want to imagine what would have happened if he didn’t know how to solder. My first-ever electronics project might have completely failed.

After we finished fixing the soldering, I moved on to firmware flashing.

That part didn’t go as smoothly as I expected either. The firmware contained many errors. Still, I managed to test the components and confirm that they were functioning.

---

### Timeline:

Started: 6 Feb 2026 | 2:30 PM
Ended: 6 Feb 2026 | 5:00 PM
Journal Entry Written: 10 Feb 2026 | 11:30 PM

>Reason for the late journal entry: I was so focused on fixing the firmware that I forgot to continue writing. That’s on me — laziness and poor time management.

---

 

---

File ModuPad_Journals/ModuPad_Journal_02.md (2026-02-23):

# PCB

### PCB Recived.

After paying the tax and duties, my PCB was finally released by the International Mail Office (IMO). The package had been held, and I was questioned about the electronics. They created a ticket for the items, and the visit itself was rough and exhausting.

Despite that, I successfully collected the PCBs — and I’m extremely satisfied with them. The manufacturing quality is top-notch. Since the components have not yet arrived, I tested the key placement using one of my own keyboard switches. The alignment turned out very good. I’m genuinely impressed with the result.

Now I’m waiting for the remaining components. Once they arrive, I’ll begin soldering and continue refining the firmware. It still lacks some features and requires core improvements, so that will be my next focus.

---

> The reason for the delayed journal entry — although the PCB arrived on 3rd February and I’m writing this on 9th February — is that I was exhausted after the IMO visit.

> On 4th February, I got distracted tracking my components. I was concerned that I might receive another notice to visit the IMO and pay additional tax. While analyzing the tracking updates, I discovered that the components had already cleared customs and were on their way to my doorstep.

>> What happens next is written inthe next journal!!!

---

**Parcel Recived:** 03-Feb-2026 | 1-PM
**Journal entry written:** 09-Feb-2026 | 8-PM

---

### Images
|  |  |  |
|---|---|---|
| 2da82686-2fa3-4be5-9c07-132f4ad8b50c | acc4d039-34a6-4ce9-af2e-8dcf436e6874 | bca0371b-0b56-4121-be27-8d3720b139bf |

---

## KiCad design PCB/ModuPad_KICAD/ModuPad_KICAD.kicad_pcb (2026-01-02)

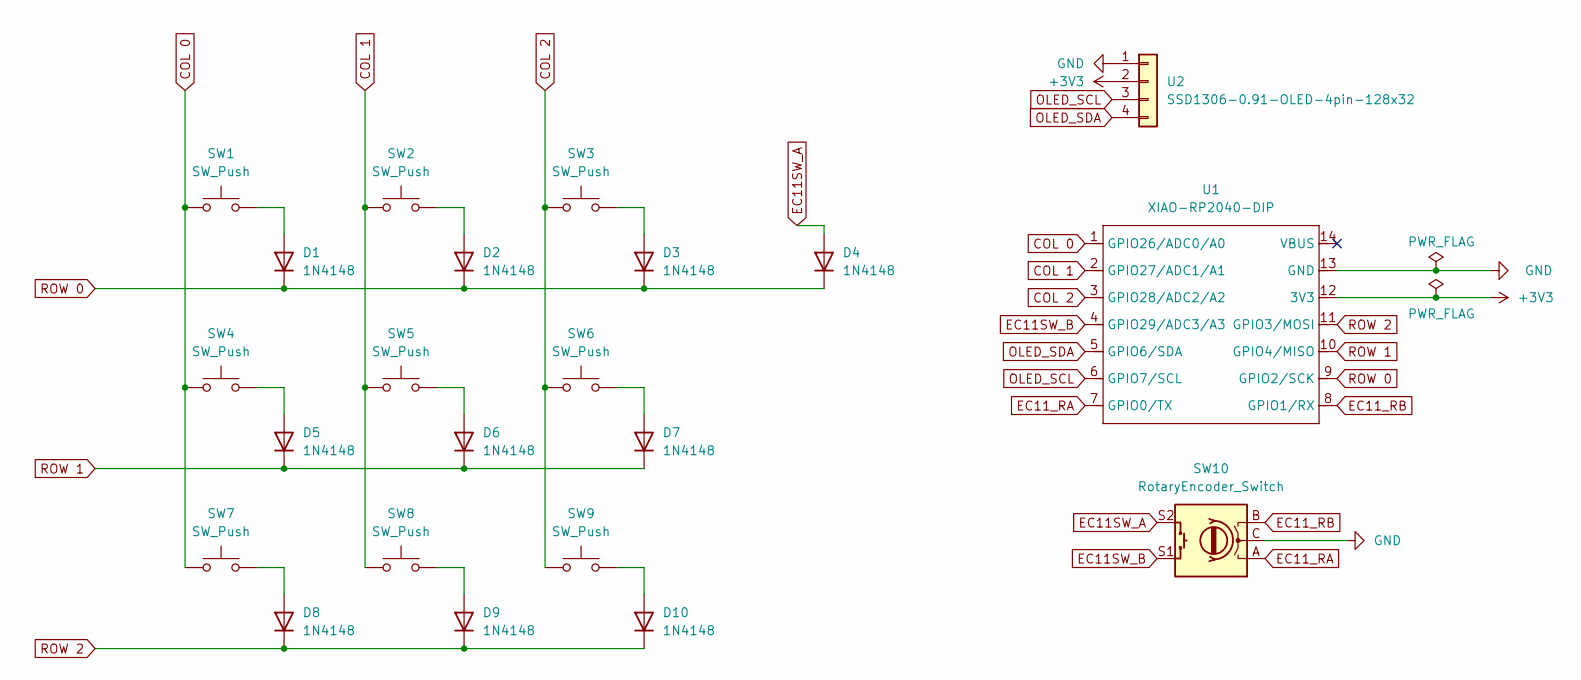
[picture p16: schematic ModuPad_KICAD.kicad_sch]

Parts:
D1, D2, D3, D4, D5, D6, D7, D8, D9, D10: 1N4148; D_DO-35_SOD27_P7.62mm_Horizontal
SW1, SW2, SW3, SW4, SW5, SW6, SW7, SW8, SW9: SW_Push; SW_Cherry_MX_1.00u_PCB
SW10: RotaryEncoder_Switch; RotaryEncoder_Alps_EC11E-Switch_Vertical_H20mm_CircularMoun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
U1: XIAO-RP2040-DIP
U2: SSD1306-0.91-OLED-4pin-128x32

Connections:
+3V3: U1.12 (3V3), U2.2
COL 0: SW1.1, SW4.1, SW7.1, U1.1 (GPIO26/ADC0/A0)
COL 1: SW2.1, SW5.1, SW8.1, U1.2 (GPIO27/ADC1/A1)
COL 2: SW3.1, SW6.1, SW9.1, U1.3 (GPIO28/ADC2/A2)
EC11SW_A: D4.2 (A), SW10.S2
EC11SW_B: SW10.S1, U1.4 (GPIO29/ADC3/A3)
EC11_RA: SW10.A, U1.7 (GPIO0/TX)
EC11_RB: SW10.B, U1.8 (GPIO1/RX)
GND: SW10.C, U1.13 (GND), U2.1
unnamed: D1.2 (A), SW1.2
unnamed: D2.2 (A), SW2.2
unnamed: D3.2 (A), SW3.2
unnamed: D5.2 (A), SW4.2
unnamed: D6.2 (A), SW5.2
unnamed: D7.2 (A), SW6.2
unnamed: D8.2 (A), SW7.2
unnamed: D9.2 (A), SW8.2
unnamed: D10.2 (A), SW9.2
OLED_SCL: U1.6 (GPIO7/SCL), U2.3
OLED_SDA: U1.5 (GPIO6/SDA), U2.4
ROW 0: D1.1 (K), D2.1 (K), D3.1 (K), D4.1 (K), U1.9 (GPIO2/SCK)
ROW 1: D5.1 (K), D6.1 (K), D7.1 (K), U1.10 (GPIO4/MISO)
ROW 2: D8.1 (K), D9.1 (K), D10.1 (K), U1.11 (GPIO3/MOSI)

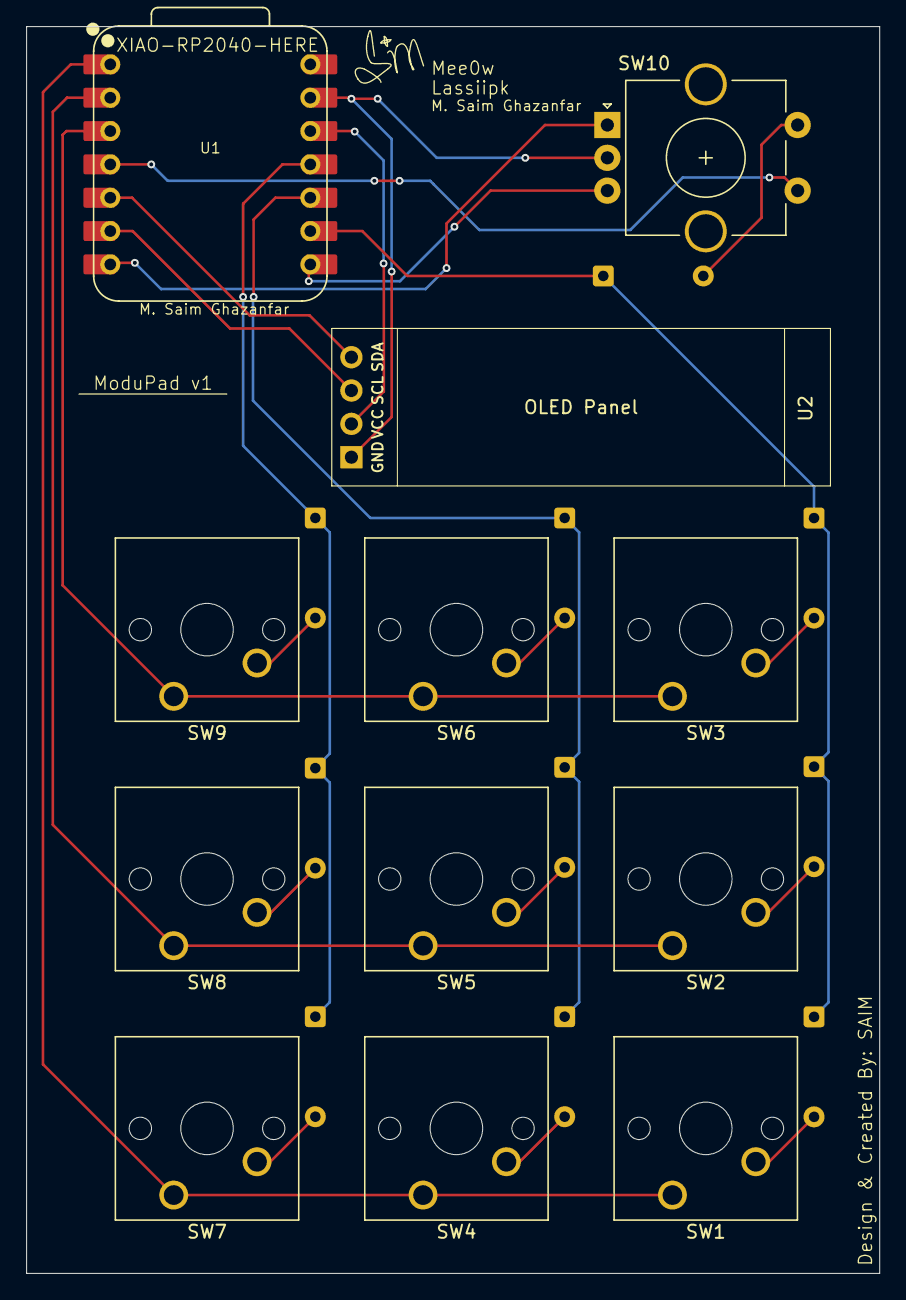
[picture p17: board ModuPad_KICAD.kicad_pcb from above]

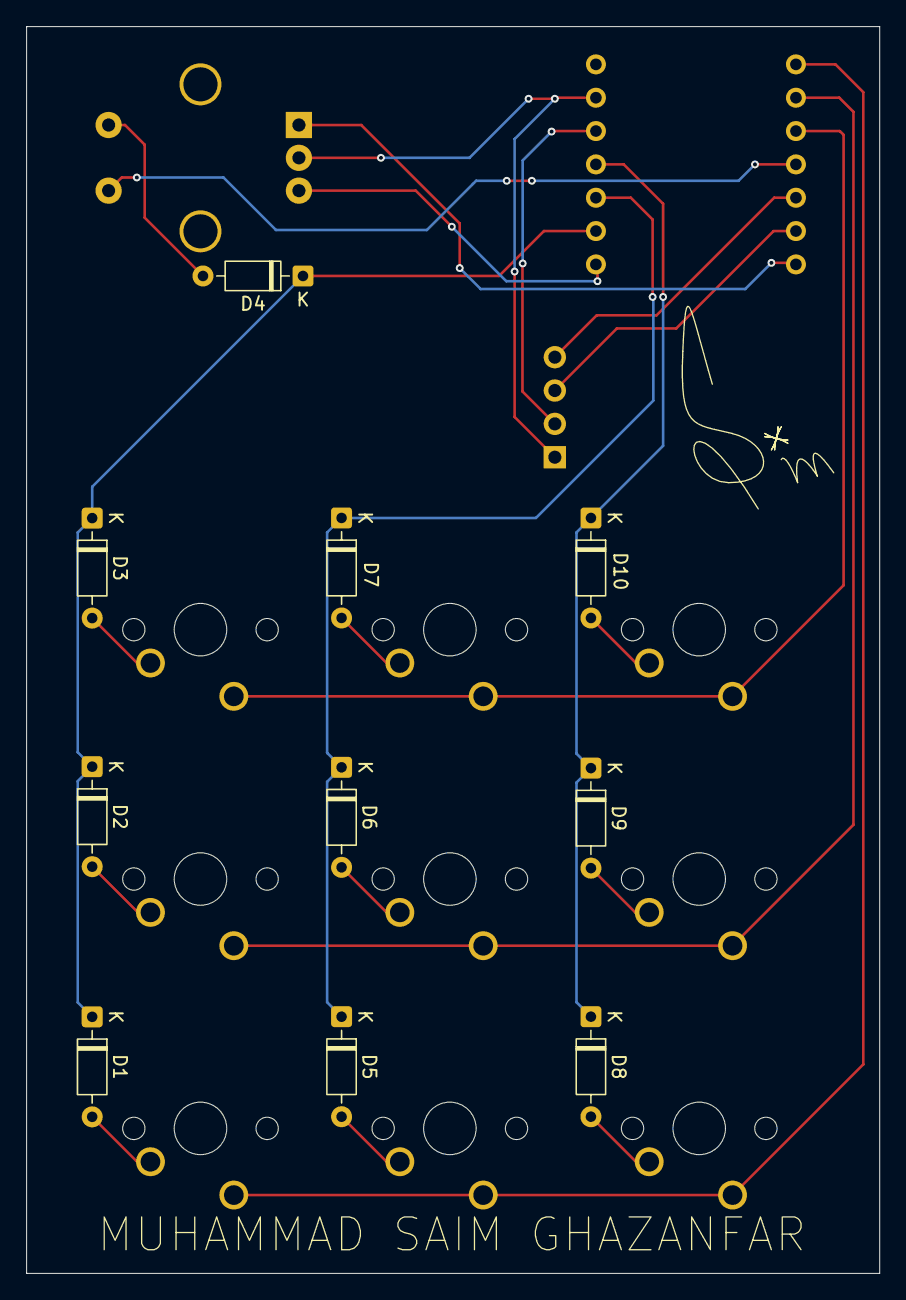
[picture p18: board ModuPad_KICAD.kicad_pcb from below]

Board: 2 copper layers, 65.0 x 95.0 mm, 22 parts (10 on the bottom side), 23 nets.

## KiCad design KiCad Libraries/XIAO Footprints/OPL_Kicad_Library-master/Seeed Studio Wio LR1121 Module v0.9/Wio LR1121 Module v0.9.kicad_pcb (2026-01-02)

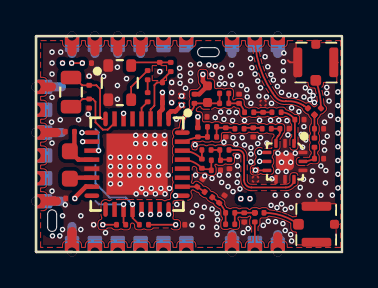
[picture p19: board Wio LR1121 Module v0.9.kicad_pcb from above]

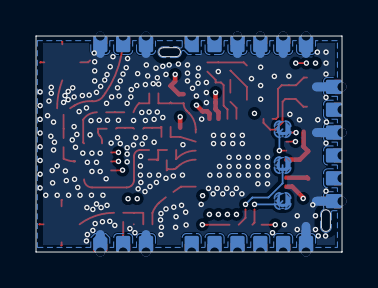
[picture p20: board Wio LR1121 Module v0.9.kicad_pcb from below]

Board: 4 copper layers, 17.0 x 12.0 mm, 69 parts (3 on the bottom side), 47 nets.

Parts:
C1, C2, C3, C4, C5, C6, C7, C8, C9, C11, C12, C13, C14, C15, C18, C19, C20, C22, C24, C25, C26, C27, C28, C29, C30, C31, C32, C33, C34, C35, C36, C37, C38, C39, C40, C41, C42, C43: C0201
FB1: L0201
J1, J2: U-FL4P-SMD-1_7X1_7X1_0MM
L1: L0402
L2, L3, L5, L6, L7, L8, L9, L10, L11, L13: L0201
L12: L0603
OSC1: X4_SMD_2_5X2_0MM
R1, R2, R3, R4, R5, R7, R8, R9: R0201
TP23, TP24, TP25: TP35S_SMD
U1: QFN12_0D5_2X2X0_55MM
U2: QFN32_0D5_5X5MM_EP3P3MM
U3: MODULE24_1D27_17X12MM
X1: X2_SMD_2X1_2MM

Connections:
2.4G_RF: C43.2, U3.2
GND_POWER: C3.2, C4.2, C5.2, C6.2, C7.2, C8.2, C11.2, C12.2, C13.2, C14.2, C15.2, C18.2, C19.2, C22.2, C25.2, C26.2, C28.2, C29.2, C30.2, C31.2, C32.2, C33.2, C35.2, C36.2, C37.2, C38.2, C40.2, C42.2, J1.2, J1.3, J1.4, J2.2, J2.3, J2.4, OSC1.1, OSC1.2, U1.2, U1.7, U1.8, U1.10, U1.12, U1.13, U2.13, U2.33, U3.1, U3.3, U3.9, U3.10, U3.13, U3.15, U3.16, U3.17, U3.18, U3.19, U3.22, U3.24
HP_LF: C1.1, L1.2, L2.1, R1.2, U2.32
LP_LF: C9.1, L6.1, L13.2, U2.31
LR1121_BUSY: U2.25, U3.8
LR1121_DIO8: U2.10, U3.11
LR1121_DIO9_INT: U2.9, U3.12
LR1121_RSTN: C42.1, R7.2, U2.6, U3.14
LR1121_SPI_MISO: U2.21, U3.7
LR1121_SPI_MOSI: U2.22, U3.6
LR1121_SPI_NSS: U2.24, U3.4
LR1121_SPI_SCK: U2.23, U3.5
MCU_DIO5: R3.1, TP23.1, U2.20
MCU_DIO6: R2.1, TP24.1, U2.19
MCU_DIO7: R5.1, TP25.1, U2.11
N18704063: C25.1, U2.7, X1.1
N18704080: C26.1, U2.8, X1.2
N18704168: L12.2, U2.14
N18704177: C31.1, L12.1, U2.12
N18704981: C9.2, C37.1, L6.2, L7.1
N18704990: C1.2, C3.1, L2.2, L3.1
N18705097: C2.1, C4.1, L3.2
N18705182: C38.1, C39.1, L7.2
N18705449: C18.1, C39.2, U1.3
N18705460: C2.2, C5.1, U1.1
N18706098: C20.2, C40.1, C41.1, L9.2
N18706198: C41.2, U1.9
N18706539: C24.1, C29.1, L10.2, L11.1
N18706650: C24.2, C27.1, C30.1, C43.1, L11.2
N18706671: C27.2, J2.1
N18712116: C14.1, L5.1, U1.11
N18712319: C36.1, FB1.2, OSC1.4
N18712325: C34.1, OSC1.3
N18712327: C34.2, R4.1
N18713044: C15.1, L5.2, R8.1, R9.1
N18751757: J1.1, R8.2
RFIO_HF: C28.1, L10.1, U2.26
RFI_N: C22.1, L8.2, L9.1, U2.29
RFI_P: C20.1, L8.1, U2.30
RFSW0_V1: C33.1, R3.2, U1.4
RFSW1_V2: C32.1, R2.2, U1.5
RFSW_VDD: C19.1, R5.2, U1.6
SUBG_RF: R9.2, U3.23
VDD_RF: C11.1, C12.1, C13.1, R7.1, U2.2, U2.15, U3.20, U3.21
VR_PA: C6.1, C7.1, C8.1, L1.1, L13.1, R1.1, U2.1
VTCXO: C35.1, FB1.1, U2.3
XTA: R4.2, U2.4

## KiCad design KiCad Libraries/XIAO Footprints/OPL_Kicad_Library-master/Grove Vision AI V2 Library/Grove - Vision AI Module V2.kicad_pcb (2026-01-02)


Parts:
BOOT1: SW_Push; SW_Push_1P1T_NO_Vertical_Wuerth_434133025816
C1, C2, C17, C18, C19: 1uF; C0402
C3: 10nF; C0402
C4, C6, C7, C9, C10, C28, C34: 4.7uF; C0402
C5, C8, C13, C20, C21, C22, C23, C24, C25, C26, C27, C29, C30, C31, C32, C35, C36, C39: 100nF; C0402
C11, C37: 10uF; C0402
C14, C15: 12pF; C0402
C16: 220nF; C0402
D1, D2, D3, D4: B5819WS; D0805_SOD323
D5, D6, D7, D8: DNP; R0402; MPN DF2S6.8FS
J1: USB_C_Receptacle_USB2.0; USB2.0-TYPE-C
J2: Conn_01x15_MountingPin; FPC_DNC_15P_1.0mm
J3: Conn_01x04_MountingPin; 4P-SMD-2.0mm-RIGHT
J5: ST-TF-MR267; SD-TF-MR267; MPN SD-TF-MR267
L1: VLS201610HBX-4R7M-1; L0806
L2, L3: 470nH; L0603
LED1: Yellow; LED0402
LED2: Green; LED0402
M1: XIAO Connector/DNP; XIAO_Socket
MIC1: MSM261D3526H1CPM; MIC6P-3.5X2.65X0.94MM
Q1, Q2, Q3, Q4, Q5: CJ1012; SOT523
R1, R4, R13, R14, R15, R19, R20, R21, R22, R40: 2.2k; R0402
R2, R3, R36: 5.1k; R0402
R5, R7, R23, R24: 10k; R0402
R6, R16, R32, R33: 100K; R0402; Power Rating 1%; MPN RC0402JR-074K7L
R8, R31, R38: 10K; R0402; Power Rating 5%; MPN RC0402JR-074K7L
R9, R12, R17, R18, R25, R27, R28: DNP; R0402
R10, R11, R37: 100k; R0402
R26, R34: 22K; R0402; Power Rating 1%; MPN RC0402JR-074K7L
R29, R30, R39: 0R; R0402
R35: 510k; R0402
RST1: SW_Push; SW_Push_1P1T_NO_Vertical_Wuerth_434133025816
TP1, TP2, TP3: Test Point; TP-D35MIL; Part Type Test Point
U1: HX6538; WLCSP65_5.6x2.3x0.56mm
U2: CH343P; QFN-16-EP_3x3mm_P0.5mm_EP1x1mm
U3: WR0331-18FF4R; X2SON-4
U4, U6: SY80004DQD; DFN6-0.5-1.5X1.5X0.65MM; MPN SY80004DQD
U5: W25Q128JWSIQ; SOIC-8_5.23x5.23mm_P1.27mm
X1: 24MHz; 4P2016

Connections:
1V8: C13.1, C19.2, C20.1, C21.1, C28.1, C29.2, Q1.1 (G), Q2.1 (G), R5.1, R21.2, R22.2, R25.1, TP2.1 (T), U1.F3 (VDDIO_SIF1), U1.G3 (VDDA_RX), U1.H5 (VDDA_TX), U1.L2 (VDDIO_SIF2), U3.1 (OUT), U5.8 (VCC)
/0V9: C4.1, C7.1, L1.2, U1.L4 (DCDC_OUT)
BOOTOPT0: D3.1 (K), R11.1, U1.F4 (BOOT_OPT)
GND: C1.2, C2.2, C3.2, C4.2, C5.2, C6.2, C7.2, C8.1, C9.2, C10.2, C11.1, C13.2, C14.2, C15.1, C17.2, C18.2, C19.1, C20.2, C21.2, C22.2, C23.2, C24.1, C25.1, C26.2, C27.1, C28.2, C29.1, C30.1, C31.2, C34.2, C35.1, C37.1, C39.1, D5.1, D6.1, D7.1, D8.1, J1.A1_B1_A12_B12 (GND), J1.S1 (SHIELD), J2.1, J2.4, J2.7, J2.10, J2.MP (MountPin), J3.4, J3.MP (MountPin), J5.S1 (SHD1), J5.S2 (SHD2), J5.S3 (SHD3), J5.S4 (SHD4), J5.T6 (VSS), LED2.1 (K), M1.13 (GND), MIC1.4 (GND), MIC1.5 (L/R), MIC1.6 (GND), Q3.2 (S), R2.2, R3.2, R10.2, R11.2, R23.2, R26.1, R34.1, R37.2, RST1.2, TP3.1 (T), U1.C5 (GND1), U1.G4 (GND2), U1.H3 (GND3), U1.L3 (GND4), U1.M2 (GND5), U1.M4 (GND6), U2.2 (GND), U2.17 (EPAD), U3.2 (GND), U3.T (GND), U4.4 (GND), U5.4 (GND), U6.4 (GND), X1.2 (1), X1.4 (3)
GROVE_5V_IN: C18.1, C34.1, C35.2, J3.3, R14.1, R15.1, R31.2, R32.2, U6.6 (IN)
I2CS0_SCL/5V: J3.1, Q4.3 (D), R14.2
I2CS0_SDA/5V: J3.2, Q5.3 (D), R15.2
M_3V3_SCL: J2.13, Q1.3 (D), R19.2
M_3V3_SDA: J2.14, Q2.3 (D), R20.2
unnamed: BOOT1.2, R4.2
unnamed: D1.2 (A), R36.2
unnamed: C9.1, C10.1, C27.2, D2.1 (K), D4.1 (K), R6.2, R8.2, U4.6 (IN)
unnamed: BOOT1.1, D3.2 (A), R36.1
unnamed: J1.A5 (CC1), R2.1
unnamed: J1.B5 (CC2), R3.1
unnamed: LED1.2 (A), R38.1
unnamed: LED1.1 (K), Q3.3 (D)
unnamed: LED2.2 (A), R24.2
unnamed: M1.12 (3V3), R39.2
unnamed: MIC1.2 (CLK), R29.1
unnamed: MIC1.3 (DATA), R30.1
unnamed: Q3.1 (G), R37.1, R40.2
unnamed: R10.1, U1.E4 (TEST_MODE)
unnamed: L1.1, U1.L5 (VX1)
unnamed: C14.1, R35.1, U1.G2 (XTAL_24M_I), X1.3 (4)
unnamed: C15.2, R35.2, U1.F1 (XTAL_24M_O), X1.1 (2)
unnamed: C16.2, U2.13 (RTS)
unnamed: R8.1, U4.1 (EN)
unnamed: C32.1, R16.1, R26.2, U4.3 (FB)
unnamed: L2.1, U4.5 (LX)
unnamed: R6.1, U4.2 (PG)
unnamed: R31.1, U6.1 (EN)
unnamed: C36.1, R33.1, R34.2, U6.3 (FB)
unnamed: L3.1, U6.5 (LX)
unnamed: R32.1, U6.2 (PG)
PA0/3V3: M1.1 (D0/A0), U1.D4 (PA0)
PA1/VMUTE/3V3: J2.11, U1.C4 (PA1)
PA2/I2CS0_SCL/3V3: M1.6 (D5/SCL), Q4.2 (S), R1.1, R17.2, U1.A4 (PA2)
PA3/I2CS0_SDA/3V3: M1.5 (D4/SDA), Q5.2 (S), R13.1, R18.2, U1.B4 (PA3)
PB0/RX0/3V3: U1.A5 (PB0), U2.4 (TXD)
PB1/TX0/3V3: U1.B5 (PB1), U2.5 (RXD)
PB2/SSPIM_DO/3V3: D7.2, J5.T3 (CMD), M1.11 (D10/MOSI), R12.2, U1.N5 (PB2)
PB3/SSPIM_DI/3V3: D5.2, J5.T7 (DAT0), M1.10 (D9/MISO), R9.2, U1.M3 (PB3)
PB4/SSPIM_SCLK/3V3: D6.2, J5.T5 (CLOCK), M1.9 (D8/SCK), R27.2, U1.N4 (PB4)
PB5/SSPIM_~CS/3V3: D8.2, J5.T2 (CD/DAT3), R28.2, U1.N3 (PB5)
PB6/UART1_RX/3V3: M1.7 (D6/TX), U1.N1 (PB6)
PB7/UART1_TX/3V3: M1.8 (D7/RX/SS), U1.M1 (PB7)
PB8/3V3: M1.3 (D2/A2), U1.L1 (PB8)
PB9/PDM_CLK/3V3: R29.2, U1.F5 (PB9)
PB10/PDM_DATA0/3V3: R30.2, U1.G5 (PB10)
PB11/3V3: M1.2 (D1/A1), U1.J3 (PB11)
QSPI_CLK: U1.C2 (QSPI_CLK), U5.6 (CLK)
QSPI_CS: R5.2, U1.B2 (QSPI_CS), U5.1 (~CS)
QSPI_D0: U1.B1 (QSPI_DIO0), U5.5 (DI(IO0))
QSPI_D1: U1.D3 (QSPI_DIO1), U5.2 (DO(IO1))
QSPI_D2: U1.A1 (QSPI_DIO2), U5.3 (IO2)
QSPI_D3: U1.E3 (QSPI_DIO3), U5.7 (IO3)
RST: C3.1, C16.1, M1.4 (D3/A3), R7.1, RST1.1, U1.E5 (RESETN)
RX_CK_N: J2.8, U1.E2 (RX_CKN)
RX_CK_P: J2.9, U1.F2 (RX_CKP)
RX_D0_N: J2.2, U1.D2 (RX_DN0)
RX_D0_P: J2.3, U1.C1 (RX_DP0)
RX_D1_N: J2.5, U1.D1 (RX_DN1)
RX_D1_P: J2.6, U1.E1 (RX_DP1)
SEN_D1/SD~INSERT: J5.G1 (SWITCH), R25.2, U1.G1 (SEN_D1)
SEN_I2CM_SCL: Q1.2 (S), R21.1, U1.A3 (SEN_I2CM_SCL)
SEN_I2CM_SDA: Q2.2 (S), R22.1, U1.B3 (SEN_I2CM_SDA)
UD+: J1.A6 (D+), J1.B6 (D+), U2.7 (D+)
UD-: J1.A7 (D-), J1.B7 (D-), U2.8 (D-)
USER_LED/1V8: R40.1, U1.K2 (SEN_D2)
USR_BTN/1V8: D1.1 (K), R23.1, U1.H1 (SEN_D0)
V33IO: C2.1, C31.1, U2.1 (VIO), U2.6 (V3)
VBUS: C1.1, C30.2, D4.2 (A), J1.A4_B4_A9_B9 (VBUS), U2.3 (VDD5), U2.9 (VBUS)
VCC_3V3: C5.1, C6.1, C8.2, C11.2, C17.1, C22.1, C23.1, C24.2, C25.2, C26.1, C32.2, C36.2, C37.2, C39.2, J2.15, J5.T4 (VDD), L2.2, L3.2, MIC1.1 (VDD), Q4.1 (G), Q5.1 (G), R1.2, R4.1, R7.2, R9.1, R12.1, R13.2, R16.2, R17.1, R18.1, R19.1, R20.1, R24.1, R27.1, R28.1, R33.2, R38.2, R39.1, TP1.1 (T), U1.D5 (VDDIO_AON), U1.M5 (VDDA_DCDC), U1.N2 (VDDIO_PIF), U3.3 (EN), U3.4 (IN)
VMAIN: D2.2 (A), M1.14 (VUSB)

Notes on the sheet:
MIPI CSI
AON 3V3
MIPI DSI
PIF 3V3
SIF only 1V8
Imax=600mA
23/11/14
Grove - Vision AI Module V2
JN.FUONG



Board: 4 copper layers, 40.0 x 20.0 mm, 112 parts (31 on the bottom side), 75 nets.

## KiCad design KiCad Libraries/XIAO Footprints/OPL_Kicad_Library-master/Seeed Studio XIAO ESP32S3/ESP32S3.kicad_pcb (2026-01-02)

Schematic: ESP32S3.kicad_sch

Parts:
ANT1: U.FL-R-SMT-1; U-FL3P-SMD-2.6X2.6X1.0MM
BAT0: VBAT; TP-80X40MIL
C1, C2, C17, C20: DNP; C0201
C3, C9, C13, C16: 2.2uF; C0201
C4, C5, C6: 4.7uF; C0201
C7, C8, C28: 10pF; C0201
C10, C21, C25, C26: 1uF; C0201
C11, C14, C15, C19, C22, C23, C29, C30: 100nF; C0201
C12: 10nF; C0201
C18: 1pF; C0201
CHG0: RED; LED-0402
D2: LMBR4010BST5G; DFN1006-2L
D3: Yellow; LED-0402
GND0: GND; TP-80X40MIL
J1, J2: DNP; H7-HALF-HOLE-2.54
J3: DF40C-30DP-0.4V(51); BTB30-0.4-7.52X2.97X1.14
K1, K2: SKTAAAE010/311021459; SW4-SMD-2.8-2.6X1.6X0.53MM
L1: 2nH; L0201
L2: 3.3nH; L0201
L3: DNP; L0201
L4: 470nH; L0603
Q1: LP0404N3T5G; PMOS_1.0_0.6_0.35MM
R1, R2: 5.1K; R0201
R3, R4: 22R; R0201
R5: 0R; R0201
R6: 499R; R0201
R7, R8, R11: 10K; R0201
R9: 100K; C0201
R10: 220K; R0201
R13: 249K; R0201
R15: 1.5K; R0201
TP1, TP2, TP3, TP4, TP5, TP6, TP7, TP8: TEST-POINT'4545'; TP-D45MIL
U1: ESP32-S3R8; QFN56G-0.4-7X7MM
U3: SGM6029CYG/TR; BGA6-0.35-0.745X10.95X0.4MM
U4: SGM40567-4.2XG/TR; WLCSP-0.4-0.92X1.16X0.4MM
U5: GD25Q64ENIGR; USON8-0.8-4X3MM
USB0: UBF31-0171; USB2.0-TYPE-C
X1: 40MHz/306011364; X4-SMD-1.6X1.2X0.35MM

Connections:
D0/A0: J2.1, J2.13 (1), U1.6 (GPIO1)
D1/A1: J2.2, J2.14 (2), U1.7 (GPIO2)
D2/A2: J2.3, J2.15 (3), J3.2, U1.8 (GPIO3)
D3/A3: J2.4, J2.16 (4), U1.9 (GPIO4)
D4/I2C_SDA: J2.5, J2.17 (5), U1.10 (GPIO5)
D5/I2C_SCL: J2.6, J2.18 (6), U1.11 (GPIO6)
D6/TX: J2.7, J2.19 (7), R6.2
D7/RX: J1.1, J1.13 (1), U1.50 (U0RXD)
D8/A8/SCK: J1.2, J1.14 (2), J3.3, U1.12 (GPIO7)
D9/A9/MISO: J1.3, J1.15 (3), J3.4, U1.13 (GPIO8)
D10/A10/MOSI: J1.4, J1.16 (4), J3.5, U1.14 (GPIO9)
EN: C21.2, K1.1 (A0), K1.3 (A1), R8.1, TP6.T, U1.4 (CHIP_PU)
ESP_USB_D+: C1.2, R4.2, TP8.T, U1.26 (GPIO20)
ESP_USB_D-: C2.2, R3.2, TP7.T, U1.25 (GPIO19)
GND: ANT1.GND1, ANT1.GND2, C1.1, C2.1, C3.2, C4.2, C5.1, C6.1, C7.2, C8.1, C9.1, C10.2, C11.1, C12.1, C13.1, C14.1, C15.1, C16.1, C17.1, C18.1, C19.1, C20.1, C21.1, C22.1, C23.2, C25.2, C26.2, C28.1, C29.1, C30.1, GND0.1, J1.6, J1.18 (6), J3.1, J3.17, J3.28, J3.29, J3.31, J3.33, J3.34, K1.2 (B0), K1.4 (B1), K2.2 (B0), K2.4 (B1), R1.1, R2.2, R9.1, R10.1, R13.1, TP1.T, U1.57 (GND), U3.A1 (GND), U4.B1 (F), U4.C2 (GND), U5.4 (GND), USB0.A1_B12 (A1/B12/GND), USB0.B1_A12 (B1/A12/GND), USB0.S1, USB0.S2, USB0.S3, USB0.S4, USB0.S5 (S1), USB0.S6 (S2), X1.2 (GND), X1.4 (GND@1)
GND5: L4.1, U3.B2 (SW)
GND6: R13.2, U3.C1 (MODE)
GPIO0: C28.2, K2.1 (A0), K2.3 (A1), R7.1, U1.5 (GPIO0)
IO10/XMCLK: J3.6, U1.15 (GPIO10)
IO11/DVP_Y8: J3.7, U1.16 (GPIO11)
IO12/DVP_Y7: J3.8, U1.17 (GPIO12)
IO13/DVP_PCLK: J3.9, U1.18 (GPIO13)
IO14/DVP_Y6: J3.10, U1.19 (GPIO14)
IO15/DVP_Y2: J3.11, U1.21 (XTAL_32K_P)
IO16/DVP_Y5: J3.12, U1.22 (XTAL_32K_N)
IO17/DVP_Y3: J3.13, U1.23 (GPIO17)
IO18/DVP_Y4: J3.14, U1.24 (GPIO18)
IO21/USER_LED: D3.-, J3.16, U1.27 (GPIO21)
IO38/DVP_VSYNC: J3.23, U1.43 (GPIO38)
IO47/DVP_HREF: J3.22, U1.37 (SPICLK_P)
IO48/DVP_Y9: J3.21, U1.36 (SPICLK_N)
MTCK/IO39/CAM_SCL: J3.24, TP5.T, U1.44 (MTCK)
MTDI/IO41/PDM_DATA: J3.26, TP3.T, U1.47 (MTDI)
MTDO/IO40/CAM_SDA: J3.25, TP4.T, U1.45 (MTDO)
MTMS/IO42/PDM_CLK: J3.27, TP2.T, U1.48 (MTMS)
unnamed: R5.1, U1.54 (XTAL_P)
unnamed: C7.1, R5.2, X1.3 (X2)
unnamed: C8.2, U1.53 (XTAL_N), X1.1 (X1)
unnamed: ANT1.D, C17.2, L2.1, L3.2
unnamed: R2.1, USB0.B5 (B5/CC2)
unnamed: C15.2, L1.2, U1.2 (VDD3P3@1), U1.3 (VDD3P3@2)
unnamed: R1.2, USB0.A5 (A5/CC1)
unnamed: C18.2, L2.2, U1.1 (LNA_IN)
unnamed: CHG0.-, U4.B2 (NCHG)
unnamed: R6.1, U1.49 (U0TXD)
unnamed: R10.2, U4.C1 (IREF)
unnamed: CHG0.+, R11.2
unnamed: D3.+, R15.1
unnamed: C20.2, L3.1
SPICLK: U1.33 (SPICLK), U5.6 (CLK)
SPICS0: U1.32 (SPICS0), U5.1 (/CS)
SPID: U1.35 (SPID), U5.5 (DIO)
SPIHD: U1.30 (SPIHD), U5.7 (/HOLD)
SPIQ: U1.34 (SPIQ), U5.2 (DO)
SPIWP: U1.31 (SPIWP), U5.3 (/WP)
USB_D+: R4.1, USB0.A6 (A6/DP1), USB0.B6 (B6/DP2)
USB_D-: R3.1, USB0.A7 (A7/DN1), USB0.B7 (B7/DN2)
VBAT: BAT0.1, C26.1, Q1.1 (D), U4.A1 (BAT)
VBUS: C10.1, C25.1, D2.+, J1.7, J1.19 (7), Q1.2 (G), R9.2, R11.1, U4.A2 (VIN), USB0.A4_B9 (A4/B9/VBUS), USB0.B4_A9 (B4/A9/VBUS)
VCC_3V3: C5.2, C6.2, C9.2, C11.2, C12.2, C13.2, C14.2, C16.2, C19.2, C23.1, C29.2, J1.5, J1.17 (5), J3.18, J3.19, L1.1, L4.2, R7.2, R8.2, R15.2, U1.20 (VDD3P3_RTC), U1.46 (VDD3P3_CPU), U1.55 (VDDA@1), U1.56 (VDDA@2), U3.A2 (VOS)
VDD_SPI: C22.2, U1.29 (VDD_SPI), U5.8 (VCC)
VIN: C3.1, C4.1, C30.2, D2.-, J3.15, J3.30, Q1.3 (S), U3.B1 (VIN), U3.C2 (EN)

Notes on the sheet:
IO40
IO39
Π Type Impedance Matching
2.Adjust C30 and C16 inward
D0/A0/Qt1
DVP_Y7
Li Battery
IO5
External Flash
Optimize the distance from the positioning hole of the shield to the pads on both sides
DVP_Y3
D10/A10/Qt9/MOSI
0.3A/Pin
2023/1/4
LC Filter
IO1
D1/A1/Qt2
CAM
IO12
ESP32-S3
USB D+
Layout note： Bottom
D9/A9/Qt8/MISO
IO42
S3 IO20/D+
PDM_CLK
LCD
XIAO Header
v1.1
IO47
IO48
IO4
Camera
DVP_Y6
Internal PSRAM
IO21
IO11
BOOT
CAM_SCL
IO10



Board: 2 copper layers, 17.8 x 21.1 mm, 72 parts (11 on the bottom side), 62 nets.

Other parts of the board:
U$7: LOGO-SEEED-NEW-0.94X8.4MM

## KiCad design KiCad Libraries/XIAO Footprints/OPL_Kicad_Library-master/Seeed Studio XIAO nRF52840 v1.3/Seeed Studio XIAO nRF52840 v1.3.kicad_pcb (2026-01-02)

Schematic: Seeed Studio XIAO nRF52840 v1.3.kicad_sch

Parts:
ANT1: ANTENNA-AN3216; ANT-SMD3P-3.2X1.6X1.04MM
BAT0: TEST-POINT'4080'; TP-80X40MIL
C1, C5, C8, C24, C34: 100nF; C0201
C2, C7: 10pF; C0201
C3, C4, C6, C9, C22, C25, C29, C30, C39, C41, C42: 2.2uF; C0201
C10: 1nF; C0402
C11: 1pF; C0201
C31: 820pF; C0201
C32, C33: 15pF; C0201
C35: 100pF; C0201
C36: 0.8pF; C0201
C37: 0.5pF; C0201
C38: 4.7nH; L0201
C40: DNP; C0201
CHG0: RED; LED-0402
D1: DIODE'0603'; SOD-523
GND0: GND; TP-80X40MIL
J1, J2: DNP; H7-HALF-HOLE-2.54
K1: BUTTON-4P; SW4-SMD-2.8-2.6X1.6X0.53MM
L3: 10uH; L0603
MIC1: MSM261D3526H1CPM; MIC6P-3.5X2.65X0.94MM
NFC1, NFC2: TEST-POINT'4080'; TP-80X40MIL
Q1: PMOS_1.00.60.35MM; PMOS_1.0_0.6_0.35MM
R1, R2: 5.1k; R0201
R3, R5, R7: 2.2k; R0201
R4, R13, R14, R15, R20: 10k; R0201
R9: 100k; R0201
R10, R11: 33R; R0201
R12, R18: 2.7k; R0201
R16: 1M_1%; R0201
R17: 510k_1%; R0201
RGB6: RGB; 4P1010
TP1, TP2, TP3, TP5: TEST-POINT'4545'; TP-D45MIL
U1: NRF52840_QF; AQFN50P700X700X85_HS-74N
U2: BQ25100; BQ25101_DSBGA_6_BQ25101
U3: LSM6DS3TR-C; LGA14-0.5-2.5X3X0.86MM
U6: 3.3V; X2SON-4
U7: DNP; USON2X3_8
USB1: USB2.0-TYPE-C
X1: 32.768KHz; X2-SMD-L1.6X1.0X0.5MM
X2: 32MHz; 4P1612

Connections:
3V3: C3.2, C6.2, C29.2, C39.1, C41.2, J1.5, J1.17 (5), R5.1, R13.1, RGB6.+, U1.A22 (VDD@A22), U1.AD14 (VDD@AD14), U1.AD23 (VDD@AD23), U1.B1 (VDD@B1), U1.W1 (VDD@W1), U1.Y2 (VDDH@Y2), U6.1 (OUT), U7.8 (VCC)
6D_INT1: U1.T2 (P0.11@T2), U3.4 (INT1)
6D_PWR: C1.2, R14.1, R15.1, U1.P2 (P1.08@P2), U3.5 (VDDIO), U3.8 (VDD), U3.12 (CS)
/CE: R20.1, U2.B1 (TS)
DEC4-6: C34.1, C42.1, L3.2, U1.B5 (DEC4@B5), U1.E24 (DEC6@E24)
GND: ANT1.2 (GND), C1.1, C2.1, C3.1, C4.2, C5.2, C6.1, C7.1, C8.1, C9.1, C10.2, C11.1, C22.1, C24.1, C25.1, C29.1, C30.2, C31.2, C32.2, C33.2, C34.2, C35.2, C36.1, C37.1, C39.2, C40.2, C41.1, C42.2, GND0.1, J1.6, J1.18 (6), K1.2 (B0), K1.4 (B1), MIC1.4 (GND@1), MIC1.5 (L/R), MIC1.6 (GND@2), R1.2, R2.1, R9.1, R18.2, R20.2, TP1.T, U1.B7 (VSS@B7), U1.F23 (VSS_PA@F23), U1.G74 (VSS_PAD), U2.C2 (VSS), U3.1 (SDO/DA0), U3.2 (SDX), U3.3 (SCX), U3.6 (GND@1), U3.7 (GND@2), U6.2 (GND), U6.T (GND), U7.4 (GND), U7.PAD (T), USB1.A1_B12 (A1/B12/GND), USB1.B1_A12 (B1/A12/GND), USB1.S1, USB1.S2, USB1.S3, USB1.S4, USB1.S5 (S1), USB1.S6 (S2), X2.2 (1), X2.4 (3)
INTERNAL_I2C_SCL: R14.2, U1.H2 (P0.27@H2), U3.13 (SCL)
INTERNAL_I2C_SDA: R15.2, U1.M2 (P0.07@M2), U3.14 (SDA)
unnamed: R1.1, USB1.A5 (A5/CC1)
unnamed: R2.2, USB1.B5 (B5/CC2)
unnamed: C2.2, U1.D2 (P0.00/XL1@D2), X1.2
unnamed: C7.2, U1.F2 (P0.01/XL2@F2), X1.1
unnamed: R7.1, RGB6.R-
unnamed: R4.1, RGB6.G-
unnamed: R10.2, U1.AD4 (D-@AD4)
unnamed: R11.2, U1.AD6 (D+@AD6)
unnamed: R3.1, RGB6.B-
unnamed: CHG0.+, R5.2
unnamed: ANT1.3, C10.1
unnamed: R12.1, R18.1, U2.B2 (ISET)
unnamed: C22.2, U1.AC5 (DECUSB@AC5)
unnamed: C24.2, U1.C1 (DEC1@C1)
unnamed: C31.1, U1.N24 (DEC5@N24)
unnamed: C33.1, U1.B24 (XC1@B24), X2.1 (2)
unnamed: C32.1, U1.A23 (XC2@A23), X2.3 (4)
unnamed: C35.1, U1.D23 (DEC3@D23)
unnamed: C36.2, C38.1, U1.H23 (ANT@H23)
unnamed: ANT1.1 (S), C37.2, C38.2
unnamed: C40.1, U1.A18 (DEC2@A18)
unnamed: L3.1, U1.B3 (DCC@B3)
P0.02_AIN0_LOW_A0_D0: J2.1, J2.13 (1), U1.A12 (P0.02/AIN0@A12)
P0.03_AIN1_LOW_A1_D1: J2.2, J2.14 (2), U1.B13 (P0.03/AIN1@B13)
P0.04_AIN2_A4_D4: J2.5, J2.17 (5), U1.J1 (P0.04/AIN2@J1)
P0.05_AIN3_A5_D5: J2.6, J2.18 (6), U1.K2 (P0.05/AIN3@K2)
P0.06_USER_BLUE: R3.2, U1.L1 (P0.06@L1)
P0.09/NFC1: NFC1.1, U1.L24 (P0.09/NFC1@L24)
P0.10/NFC2: NFC2.1, U1.J24 (P0.10/NFC2@J24)
P0.13_HICHG: R12.2, U1.AD8 (P0.13@AD8)
P0.14_~READ_BAT: R17.2, U1.AC9 (P0.14@AC9)
P0.16_PDM_DATA: MIC1.3 (DATA), U1.AC11 (P0.16@AC11)
P0.17_~CHG: CHG0.-, U1.AD12 (P0.17@AD12), U2.C1 (PRETERM)
P0.20_QSPI_SIO_0: U1.AD16 (P0.20@AD16), U7.5 (DI)
P0.21_QSPI_SCK: C11.2, U1.AC17 (P0.21@AC17), U7.6 (CLK)
P0.22_QSPI_SIO_2: U1.AD18 (P0.22@AD18), U7.3 (~WP)
P0.23_QSPI_SIO_3: U1.AC19 (P0.23@AC19), U7.7 (~HOLD)
P0.24_QSPI_SIO_1: U1.AD20 (P0.24@AD20), U7.2 (DO)
P0.25_QSPI_CSN: U1.AC21 (P0.25@AC21), U7.1 (~CS)
P0.26_USER_RED: R7.2, U1.G1 (P0.26@G1)
P0.28_AIN4_LOW_A2_D2: J2.3, J2.15 (3), U1.B11 (P0.28/AIN4@B11)
P0.29_AIN5_LOW_A3_D3: J2.4, J2.16 (4), U1.A10 (P0.29/AIN5@A10)
P0.30_USER_GREEN: R4.2, U1.B9 (P0.30/AIN6@B9)
P0.31_AIN7_BAT: R16.2, R17.1, U1.A8 (P0.31/AIN7@A8)
P1.00_PDM_CLK: MIC1.2 (CLK), U1.AD22 (P1.00@AD22)
P1.10_MIC_PWR: C8.2, MIC1.1 (VDD), U1.A20 (P1.10@A20)
P1.11_TX_D6: J2.7, J2.19 (7), U1.B19 (P1.11@B19)
P1.12_RX_D7: J1.1, J1.13 (1), U1.B17 (P1.12@B17)
P1.13_SCK_D8: J1.2, J1.14 (2), U1.A16 (P1.13@A16)
P1.14_MISO_D9: J1.3, J1.15 (3), U1.B15 (P1.14@B15)
P1.15_MOSI_D10: J1.4, J1.16 (4), U1.A14 (P1.15@A14)
PWR_LED: U1.R24 (P1.06@R24)
RESET: C5.1, K1.1 (A0), K1.3 (A1), R13.2, TP2.T, U1.AC13 (P0.18/RESET@AC13)
SWDCLK: TP3.T, U1.AA24 (SWDCLK@AA24)
SWDIO: TP5.T, U1.AC24 (SWDIO@AC24)
USB_D+: R11.1, USB1.A6 (A6/DP1), USB1.B6 (B6/DP2)
USB_D-: R10.1, USB1.A7 (A7/DN1), USB1.B7 (B7/DN2)
VBAT: BAT0.1, C30.1, Q1.1 (D), R16.1, U2.A1 (OUT)
VBUS: C9.2, C25.2, D1.+, J1.7, J1.19 (7), Q1.2 (G), R9.2, U1.AD2 (VBUS@AD2), U2.A2 (IN), USB1.A4_B9 (A4/B9/VBUS), USB1.B4_A9 (B4/A9/VBUS)
VIN: C4.1, D1.-, Q1.3 (S), U6.3 (EN), U6.4 (IN)

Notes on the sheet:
Linus.Liao
2.Change C32,C33 to 15pF
zhihuai.Zhou
Initail Version
the TS and VSS.
NTC:
2021.2.2
Set P0.14 to output Sink only to enable BAT voltage read;
v1.0
2.Add C11 to to resolve the issue of data corruption during Flash read operations.
1.Change 32M Crystal
Disable Temp sense function,
2025.6.20
1.Remove R8
use fixed 10k resistor between
2024.3.19

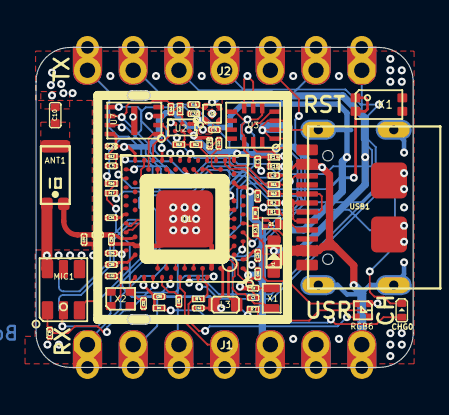
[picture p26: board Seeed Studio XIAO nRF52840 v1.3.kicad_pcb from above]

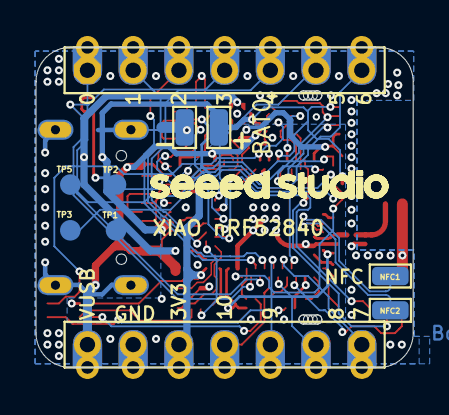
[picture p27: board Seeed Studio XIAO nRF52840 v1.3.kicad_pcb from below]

Board: 2 copper layers, 21.0 x 17.8 mm, 80 parts (9 on the bottom side), 67 nets.

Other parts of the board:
U$14: LOGO-SEEED-NEW-1_3X13MM
UNK_HOLE_0: dummyfp0
UNK_HOLE_1: dummyfp1
UNK_HOLE_2: dummyfp2
UNK_HOLE_3: dummyfp3
UNK_HOLE_4: dummyfp4
UNK_HOLE_5: dummyfp5
UNK_HOLE_6: dummyfp6
UNK_HOLE_7: dummyfp7

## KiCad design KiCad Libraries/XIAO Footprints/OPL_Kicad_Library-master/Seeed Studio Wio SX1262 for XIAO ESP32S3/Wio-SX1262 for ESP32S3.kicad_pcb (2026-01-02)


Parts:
C1: 100nF; C0402; Voltage Rating 16V,X7R; MPN CC0402KRX7R7BB104
D1: Green; LED-0603; MPN 19-217/G7C-AN1P2/3T
J1, J2: Header 1x7 2.54mm; H7-2.54; Part Type Header
J3: 30pin; BTB2X15-FEMALE-8.6X2.94X3.9MM; Rating DC0.3A; MPN BTB SCOKET P0.40
K1: TS-1185E; BUTTON2P_3_9X3X2MM; MPN TS-1185E
R1, R3: 10K; R0402; Power Rating 5%; MPN RC0402JR-0710KL
R2: 330R; R0402; Power Rating 1%; MPN RC0402FR-07330RL
R4, R5, R6, R7: 47R; R0402; Power Rating 1%; MPN RC0201FR-0745RL
TP1: Test Point; TP-D3_5c2_2mm; Part Type Test Point
U1: Wio-SX1262; MODULE12P-1.27-11X11.6MM; MPN Wio-SX1262

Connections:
+3V3: C1.1, J2.3, J3.23, J3.25, R1.2, R3.2, U1.8 (VCC)
GND: C1.2, J2.2, J3.2, J3.3, J3.5, J3.27, K1.1, R2.1, U1.7 (GND1), U1.10 (GND2)
GPIO14: J3.20
GPIO15: J3.22
GPIO16: J3.24
GPIO17: J3.26
GPIO18: J3.28
GPIO21: J3.29, K1.2, R3.1
GPIO47: J3.17
GPIO48: D1.1 (+), J3.19
LORA_BUSY: J1.2, J3.11, U1.11 (BUSY)
LORA_DIO1: J1.1, J3.13, U1.12 (DIO1)
LORA_RF_SW1: J1.5, J3.15, U1.1 (RF_SW1)
LORA_RST: J1.3, J3.7, R1.1, U1.5 (RST)
LORA_SPI_MISO: J2.5, J3.8, R4.1
LORA_SPI_MOSI: J2.4, J3.10, R5.1
LORA_SPI_NSS: J1.4, J3.9, R7.1
LORA_SPI_SCK: J2.6, J3.6, R6.1
unnamed: D1.2 (-), R2.2
unnamed: R4.2, U1.2 (MISO)
unnamed: R5.2, U1.3 (MOSI)
unnamed: R7.2, U1.6 (NSS)
unnamed: R6.2, U1.4 (SCK)
VIN: J2.1, J3.1, J3.30

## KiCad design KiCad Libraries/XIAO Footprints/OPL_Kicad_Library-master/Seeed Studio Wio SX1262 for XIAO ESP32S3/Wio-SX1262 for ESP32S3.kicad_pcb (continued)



Board: 2 copper layers, 17.8 x 21.4 mm, 15 parts (5 on the bottom side), 18 nets.

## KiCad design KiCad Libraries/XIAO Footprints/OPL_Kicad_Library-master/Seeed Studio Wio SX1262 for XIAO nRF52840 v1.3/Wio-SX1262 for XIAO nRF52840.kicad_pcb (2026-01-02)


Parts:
C1: 100nF; C0402; Voltage Rating 16V,X7R; MPN CC0402KRX7R7BB104
J1, J2: Header 1x7 2.54mm; H7-2.54; Part Type Header
K1: TS-1188E 6C81; SW4-SMD-7.0X3.5X3.5MM-90D; MPN TS-1188E 6C81; not fitted
R1: 10K; R0402; Power Rating 5%; MPN RC0402JR-0710KL
R2: 10K; R0402; Power Rating 5%; MPN RC0402JR-0710KL; not fitted
R3, R4, R5, R6: 22R; R0402; Power Rating 1%; MPN RC0402FR-0722RL
U1: Wio-SX1262; MODULE12P-1.27-11X11.6MM; MPN Wio-SX1262

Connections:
+3V3: C1.1, J2.3, R1.2, R2.2, U1.8 (VCC)
/D0: J1.1, K1.2, R2.1
/LORA_BUSY: J1.4, U1.11 (BUSY)
/LORA_DIO1: J1.2, U1.12 (DIO1)
/LORA_RF_SW1: J1.6, U1.1 (RF_SW1)
/LORA_RST: J1.3, R1.1, U1.5 (RST)
/LORA_SPI_MISO: J2.5, R4.1
/LORA_SPI_MOSI: J2.4, R5.1
/LORA_SPI_NSS: J1.5, R3.1
/LORA_SPI_SCK: J2.6, R6.1
GND: C1.2, J2.2, K1.1, K1.3 (S1), K1.4 (S2), U1.7 (GND1), U1.10 (GND2)
unnamed: R4.2, U1.2 (MISO)
unnamed: R5.2, U1.3 (MOSI)
unnamed: R3.2, U1.6 (NSS)
unnamed: R6.2, U1.4 (SCK)
VIN: J2.1


Board: 2 copper layers, 17.8 x 21.4 mm, 11 parts (0 on the bottom side), 15 nets.

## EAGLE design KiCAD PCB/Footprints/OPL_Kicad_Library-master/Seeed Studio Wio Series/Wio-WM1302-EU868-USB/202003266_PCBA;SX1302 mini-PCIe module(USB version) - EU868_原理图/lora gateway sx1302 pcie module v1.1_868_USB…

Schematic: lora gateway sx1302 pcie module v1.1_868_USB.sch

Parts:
ANT1: U.FL-R-SMT-1(10); U-FL3P-SMD-2.6X2.6X1.0MM
ANT2: DNP; U-FL3P-SMD-2.6X2.6X1.0MM
C1, C12, C15, C19, C23, C25, C26, C29, C32, C41, C43, C45, C65, C67, C80, C83, C86, C88: 100nF; C0402
C2, C75: 2.2pF; C0402
C3, C92: 10uF; C0603
C4, C8, C11, C16, C17, C18, C64: 56pF; C0402
C5, C6, C9, C10: 3.6pF; C0402
C7, C91: 5.6pF; C0402
C13, C20, C21, C24, C28, C35, C39, C40, C42, C44, C47, C48, C76, C87, C89: 1uF; C0402
C14, C38, C57, C66, C81, C84: 10pF; C0402
C22, C27, C33: 10uF; C0603@1
C30, C56, C74, C77, C78, C79: DNP; C0402
C31: DNP; C0603@1
C34, C46, C63: 470nF; C0402
C36: 47nF; C0402
C37: 47pF; C0402
C49: 4.7uF; C0603
C50, C62, C85: 10nF; C0402
C51: 1nF; C0402
C52, C55: 100pF; C0402
C53, C60, C61: 3.3pF; C0402
C54: 39pF; C0402
C58: 1.3pF; C0402
C59, C68, C73: 1.8pF; C0402
C69, C70, C71, C72: 10uF; C0805
C82: 2.7pF; C0402
C90: 2.2uF; C0603
D1, D4: Green; LED-0402
D2: Red; LED-0402
D3: Blue; LED-0402
D5: LXES15AAA1-153; ESD-0402
D6: DNP; ESD-0402
D7: BAT54XV2T1G; SOD-523
FB1: BLM15PD121SN1D; F0402
J1: DNP; PCIE52P-0.8-50.95X30MM
L1: LQP15MN1N2B02D; L0402
L2: LQW15AN6N8G00D; L0402
L4: 0R; F0603
L5: LQH44PN1R0NP0L; L4.4X3.0MM
L6, L14, L20: MLZ2012M150WT; L0805
L7, L15, L18, L21: DNP; L0402
L8: LQW15AN3N0B00; L0402
L9: LQW15AN47NJ00D; L0402
L10: LQW15AN2N5B00D; L0402
L11: LQW15AN4N7C00D; L0402
L12, L13: LQW15AN12NG00D; L0402
L16: LQW15AN7N5G00D; L0402
L17, L24: LQW15AN5N6C10D; L0402
L22: LQW15AN15NG00D; L0402
Q8: CJ2101; SOT-323
Q10: CJ2102; SOT-323
R1, R4, R33, R34, R38, R42, R57, R65, R71: 10k; R0402
R2, R7: 0R; R0603
R3, R8, R11, R12, R43, R44, R46, R49, R51, R55, R56, R59, R60, R61, R62, R63, R67, R70, R72, R73, R74, R75, R76, R81: DNP; R0402
R5, R10, R14, R15, R16, R39, R40, R41: 100R; R0402
R6, R9, R37: 220R; R0402
R13, R35, R52: DNP; R0603
R17, R18, R19, R20, R21, R22, R23, R24, R25, R26, R27, R28, R29, R36, R45, R48, R50, R53, R54, R69, R77: 0R; R0402
R30, R31, R32: 680R; R0402
R47, R79: 1k; R0402
R58, R68: 4.7k; R0402
R64, R66: 22R; R0402
R78, R82: 100k; R0402
R80: 10R; R0402
R83, R87: 200k_1%; R0402
S1, S2, S3, S4, S5, S6: 323030226; SHIELD_CLIP
TP1, TP2, TP3, TP4, TP5, TP6, TP7, TP8, TP9, TP10, TP14: TEST-POINT-35; TP_3535
TP15: TEST-POINT'4545'; TP-D45MIL
U1: SX1302IMLTRT; QFN68-0.35-7X7X0.75MM
U2, U8, U10: HDF866A3-S6; FILTER6P-1.1-3X3X1.3MM
U3, U4: DNP; SOT-23-5
U5, U7: SX1250IMLTRT; QFN24G-0.5-4X4MM
U6: MP2161GJ; TSOT23-8
U9: SKY66420-11; MODULE16P-0.5-3X3X0.75MM
U11: SX1262IMLTRT; QFN24G-0.5-4X4MM
U12: STM32L412K8U6; UFQFPN32-0.5-5X5MM
U13: STTS751; UDFN-6L
X1: DSB221SDN; X4-SMD-2.5X2.0X1.0MM
X3: 32.768kHz; X2-SMD-3.2X1.5X0.55MM

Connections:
32MHZ: R6.2, R9.2, R37.2, X1.3 (OUT)
1302_CS: R33.2, R43.1, U1.1 (HOST_CSN), U12.10 (PA4)
1302_RESET: C1.2, D7.-, R1.2, U1.7 (RESET), U12.8 (PA2)
1302_RESET_HOST: D7.+, R59.1
CONFIG_OK: R31.1, U1.66 (GPIO0)
DM: J1.36, R66.1
DP: J1.38, R64.1
FEM_CS: R14.2, R34.1, U1.10 (RADIO_CTRL0), U3.3 (CE)
FEM_PA_ON: R15.2, U1.16 (RADIO_CTRL4)
GND: ANT1.GND1, ANT1.GND2, ANT2.GND1, ANT2.GND2, C2.1, C3.1, C5.1, C7.1, C9.1, C12.1, C13.1, C15.1, C16.1, C17.1, C18.1, C19.1, C20.1, C21.1, C22.1, C23.1, C24.1, C25.1, C26.1, C27.1, C28.1, C29.1, C30.1, C31.1, C32.1, C33.1, C34.1, C35.1, C36.1, C37.1, C39.1, C40.1, C41.1, C42.1, C43.1, C44.1, C45.1, C46.1, C47.1, C48.1, C49.1, C50.1, C51.1, C52.1, C55.1, C56.1, C57.1, C58.1, C60.2, C61.2, C62.1, C63.2, C65.2, C67.2, C69.1, C70.1, C71.1, C72.1, C73.2, C74.2, C76.1, C77.2, C78.2, C80.1, C81.2, C82.2, C83.1, C84.2, C85.1, C86.1, C87.1, C88.1, C89.1, C90.1, C92.1, D1.-, D2.-, D3.-, D4.-, D5.1, D6.1, J1.4 (GND), J1.9 (GND), J1.15 (GND), J1.18 (GND), J1.21 (GND), J1.26 (GND), J1.27 (GND), J1.29 (GND), J1.34 (GND), J1.35 (GND), J1.37 (GND), J1.40 (GND), J1.43 (GND), J1.50 (GND), J1.S1 (GND), J1.S2 (GND), Q10.2 (S), R1.1, R4.1, R11.1, R12.1, R17.2, R53.1, R53.2, R54.1, R54.2, R55.1, R55.2, R57.2, R73.1, R74.1, R74.2, R87.1, S1.S1, S1.S2, S1.S3, S1.S4, S1.S5, S2.S1, S2.S2, S2.S3, S2.S4, S2.S5, S3.S1, S3.S2, S3.S3, S3.S4, S3.S5, S4.S1, S4.S2, S4.S3, S4.S4, S4.S5, S5.S1, S5.S2, S5.S3, S5.S4, S5.S5, S6.S1, S6.S2, S6.S3, S6.S4, S6.S5, TP3.T, U1.6 (GND), U1.9 (GND), U1.15 (GND), U1.24 (GND), U1.25 (GND), U1.39 (GND), U1.46 (GND), U1.55 (GND), U1.62 (GND), U1.69 (GND), U2.1 (GND), U2.3 (GND), U2.4 (GND), U2.6 (GND), U3.2 (VSS), U4.2 (VSS), U5.7 (GND), U5.20 (GND), U5.PAD, U6.4 (PGND), U6.6 (AGND), U7.7 (GND), U7.20 (GND), U7.PAD, U8.1 (GND), U8.3 (GND), U8.4 (GND), U8.6 (GND), U9.10 (GND), U9.12 (GND), U9.17 (EPAD), U10.1 (GND), U10.3 (GND), U10.4 (GND), U10.6 (GND), U11.2 (GND), U11.5 (GND), U11.8 (GND), U11.20 (GND), U11.PAD, U12.16 (VSS), U12.32 (VSS), U12.PAD, U13.4 (ADDR/!THERM), U13.5 (GND), X1.2 (GND)
HOST_CS0: J1.51, R43.2
HOST_CS1: J1.25, R51.2
HOST_IO1: J1.33, R61.2
HOST_IO2: J1.31, R63.2
HOST_IO3: J1.23
HOST_IO4: J1.8, R67.2
HOST_IO5: J1.10, R60.2
HOST_IO6: J1.12
HOST_MISO: R39.1, R44.2
HOST_MOSI: J1.49, R46.2
HOST_RST: J1.22, R59.2, R77.2
HOST_SCK: J1.45, R49.2
I2C_SCL: R68.2, R76.1, R81.1, U12.29 (PB6), U13.1 (SCL)
I2C_SDA: R58.2, R70.1, R75.1, U12.30 (PB7), U13.6 (SDA)
MCU_RESET: C85.2, R71.2, R77.1, TP5.T, U12.4 (NRST)
MISO: R44.1, R45.1, U1.2 (HOST_MISO), U11.16 (MISO)
MISO_A: U1.42 (RADIO_A_MISO), U5.16 (MISO)
MISO_B: U1.33 (RADIO_B_MISO), U7.16 (MISO)
MOSI: R5.2, R40.2, R46.1, R48.1
MOSI_A: U1.67 (RADIO_A_MOSI), U5.17 (MOSI)
MOSI_B: U1.19 (RADIO_B_MOSI), U7.17 (MOSI)
unnamed: C11.2, U9.2 (RX)
unnamed: TP15.T, U6.1 (PG)
unnamed: C8.1, R11.2, R52.2, U8.5 (OUT)
unnamed: C2.2, L11.2, R52.1, U8.2 (IN)
unnamed: C11.1, R13.2, U2.2 (IN)
unnamed: C4.2, U9.1 (TX)
unnamed: C68.1, C74.1, C75.2
unnamed: C65.1, L18.2, R36.2, U11.1 (VDD_IN)
unnamed: C66.2, R37.1
unnamed: L5.1, U6.3 (SW)
unnamed: R83.1, R87.2, U6.7 (FB)
unnamed: R3.1, R4.2, X1.1 (ENABLE)
unnamed: C14.1, U5.3 (XTA)
unnamed: C62.2, L4.1, R3.2, X1.4 (VDD)
unnamed: R5.1, U1.3 (HOST_MOSI)
unnamed: D4.+, R47.2
unnamed: R10.1, U1.4 (HOST_SCK)
unnamed: R82.2, U6.8 (EN)
unnamed: R8.1, U4.3 (CE)
unnamed: C14.2, R6.1
unnamed: L6.2, U5.8 (DCC_SW)
unnamed: C34.2, L6.1, L7.2, U5.6 (VREG)
unnamed: C64.1, C82.1, L24.2
unnamed: R19.1, U1.34 (RADIO_B_CLK_I)
unnamed: C16.2, R14.1, U9.4 (CSD)
unnamed: C38.1, U7.3 (XTA)
unnamed: C36.2, C37.2, L9.2, U5.1 (VR_PA)
unnamed: C38.2, R9.1
unnamed: L14.2, U7.8 (DCC_SW)
unnamed: C46.2, L14.1, L15.2, U7.6 (VREG)
unnamed: C54.2, L11.1
unnamed: C7.2, C53.2, C54.1, L10.2
unnamed: C4.1, C8.2, R12.2
unnamed: C17.2, R15.1, U9.5 (CPS)
unnamed: C18.2, R16.1, U9.6 (CTX)
unnamed: R17.1, U1.20 (SP_VALID)
unnamed: R18.1, U1.32 (RADIO_B_IQ3)
unnamed: R20.1, U1.35 (RADIO_B_IQ0)
unnamed: R24.1, U1.41 (RADIO_A_IQ3)
unnamed: R21.1, U1.36 (RADIO_B_IQ1)
unnamed: R22.1, U1.37 (RADIO_B_IQ4)
unnamed: R23.1, U1.38 (RADIO_B_IQ2)
unnamed: R25.1, U1.43 (RADIO_A_CLK_I)
unnamed: R26.1, U1.44 (RADIO_A_IQ0)
unnamed: R27.1, U1.45 (RADIO_A_IQ1)
unnamed: R28.1, U1.48 (RADIO_A_IQ4)
unnamed: R29.1, U1.49 (RADIO_A_IQ2)
unnamed: D3.+, R32.2
unnamed: D2.+, R31.2
unnamed: D1.+, R30.2
unnamed: Q8.1 (G), Q10.3 (D), R78.2
unnamed: C1.1, R80.1
unnamed: L1.1, U9.16 (VCC1)
unnamed: L2.1, L8.1, U9.13 (PA_OUT)
unnamed: C56.2, C57.2, L8.2, L16.1
unnamed: C58.2, L16.2, U9.11 (TX_IN)
unnamed: C59.2, C60.1, L17.1, U9.9 (ANT)
unnamed: C61.1, C91.1, L17.2, L24.1
unnamed: C66.1, U11.3 (XTA)
unnamed: ANT1.D, C64.2, D5.2
unnamed: R35.2, R62.1, R69.2, U10.2 (IN)
unnamed: C63.1, L18.1, L20.1, U11.7 (VREG)
unnamed: R35.1, U9.7 (LNA_IN), U10.5 (OUT)
unnamed: L20.2, U11.9 (DCC_SW)
unnamed: J1.47, R39.2
unnamed: R40.1, U11.17 (MOSI)
unnamed: R41.1, U11.18 (SCK)
unnamed: C6.1, C10.1, C75.1, R13.1, U2.5 (OUT)
unnamed: R69.1, U9.8 (RX_FLT)
unnamed: C78.1, C79.1, L21.2
unnamed: ANT2.D, C79.2, D6.2
unnamed: C59.1, C91.2
unnamed: C77.1, L21.1, R62.2
unnamed: R65.2, U13.2 (!EVENT)
unnamed: C52.2, FB1.1, L1.2, U9.15 (VCC0)
unnamed: R64.2, U12.22 (PA12)
unnamed: R66.2, U12.21 (PA11)
unnamed: C92.2, Q10.1 (G), R79.2
unnamed: R56.2, R57.1, U12.31 (BOOT0)
unnamed: R72.2, R73.2, U12.6 (PA0-CLK_IN)
unnamed: C81.1, U12.2 (PC14-OSC32_IN), X3.2
unnamed: C84.1, U12.3 (PC15-OSC32_OUT), X3.1
unnamed: J1.14, R76.2
unnamed: J1.16, R70.2
unnamed: J1.30, R81.2
unnamed: J1.32, R75.2
PPS: J1.19, TP2.T, U1.8 (PPS), U12.27 (PB4)
RADIO_A_CLK_32M: R25.2, R72.1, U5.14 (BUSY)
RADIO_A_CLK_O: R28.2, U5.11 (DIO5)
RADIO_A_CSN: U1.68 (RADIO_A_CSN), U5.19 (NSS)
RADIO_A_IQ_0: R26.2, U5.13 (DIO1)
RADIO_A_IQ_1: R27.2, U5.12 (DIO2)
RADIO_A_IQ_2: R29.2, U5.5 (DIO3)
RADIO_A_IQ_3: R24.2, U5.21 (DIO4)
RADIO_A_RESET: U1.13 (RADIO_CTRL3), U5.15 (NRESET)
RADIO_A_RFIN: C6.2, L12.2, U5.23 (RFI_N)
RADIO_A_RFIP: C5.2, L12.1, U5.22 (RFI_P)
RADIO_B_CLK_32M: R19.2, U7.14 (BUSY)
RADIO_B_CLK_O: R22.2, U7.11 (DIO5)
RADIO_B_CSN: U1.18 (RADIO_B_CSN), U7.19 (NSS)
RADIO_B_IQ0: R20.2, U7.13 (DIO1)
RADIO_B_IQ_1: R21.2, U7.12 (DIO2)
RADIO_B_IQ_2: R23.2, U7.5 (DIO3)
RADIO_B_IQ_3: R18.2, U7.21 (DIO4)
RADIO_B_RESET: U1.28 (RADIO_CTRL9), U7.15 (NRESET)
RADIO_B_RFIN: C10.2, L13.2, U7.23 (RFI_N)
RADIO_B_RFIP: C9.2, L13.1, U7.22 (RFI_P)
RFO: C53.1, L9.1, L10.1, U5.24 (RFO)
RX_ON: R32.1, U1.59 (GPIO4)
SCK: R10.2, R41.2, R49.1, R50.1
SCK_A: U1.65 (RADIO_A_SCK), U5.18 (SCK)
SCK_B: U1.21 (RADIO_B_SCK), U7.18 (SCK)
STM32_MISO: R45.2, U12.12 (PA6)
STM32_MOSI: R48.2, U12.13 (PA7)
STM32_SCK: R50.2, U12.11 (PA5)
SWCLK: TP7.T, U12.24 (PA14)
SWDIO: TP8.T, U12.23 (PA13)
SX1261_BUSY: R67.1, U11.14 (BUSY), U12.9 (PA3)
SX1261_CS: R42.1, R51.1, U11.19 (NSS), U12.14 (PB0)
SX1261_IO1: R61.1, U1.54 (GPIO7), U11.13 (DIO1), U12.15 (PB1)
SX1261_IO2: R63.1, U11.12 (DIO2)
SX1261_IO3: TP9.T, U11.6 (DIO3)
SX1261_RFIN: C68.2, L22.2, U11.22 (RFI_N)
SX1261_RFIP: C73.1, L22.1, U11.21 (RFI_P)
SX1261_RST: R38.1, R60.1, U11.15 (NRESET), U12.18 (PA8)
SX1302_GPIO8: U1.53 (GPIO8), U12.26 (PB3)
TX_ON: R30.1, U1.63 (GPIO2)
TX_RX_SW: R16.2, U1.12 (RADIO_CTRL2)
VCCIO: C3.2, C19.2, C20.2, C25.2, C28.2, C41.2, C42.2, C45.2, C47.2, C76.2, C80.2, C83.2, C86.2, C87.2, C88.2, C89.2, C90.2, Q8.3 (D), R33.1, R34.2, R56.1, R58.1, R65.1, R68.1, R71.1, R80.2, TP1.T, U1.14 (VCC_IO), U1.30 (VCC_IO), U1.47 (VCC_IO), U1.61 (VCC_IO), U12.1 (VDD), U12.5 (VDDA), U12.17 (VDD), U13.3 (VDD)
VCC_1V2: C12.2, C13.2, C23.2, C24.2, C29.2, C40.2, C43.2, C44.2, C71.2, C72.2, L5.2, R79.1, R83.2, TP14.T, U1.5 (VCC_CORE), U1.23 (VCC_CORE), U1.40 (VCC_CORE), U1.56 (VCC_CORE), U6.5 (OUT)
VCC_FEM: C26.2, C27.2, C49.2, C50.2, C51.2, C55.2, FB1.2, L2.2, R2.2, TP6.T, U3.5 (VOUT)
VCC_RADIO: C21.2, C32.2, C33.2, C35.2, C39.2, C48.2, C67.1, L4.2, L7.1, L15.1, R7.2, R36.1, R38.2, R42.2, TP10.T, U4.5 (VOUT), U5.2 (VDD_IN), U5.9 (VBAT_RF), U5.10 (VBAT_DIO), U7.2 (VDD_IN), U7.9 (VBAT_RF), U7.10 (VBAT_DIO), U11.10 (VBAT), U11.11 (VBAT_IO)
VIN: C15.2, C22.2, C30.2, C31.2, C69.2, C70.2, J1.2 (3V3), J1.24 (3V3), J1.39 (3V3), J1.41 (3V3), J1.52 (3V3), Q8.2 (S), R2.1, R7.1, R8.2, R47.1, R78.1, R82.1, TP4.T, U3.1 (VIN), U4.1 (VIN), U6.2 (VIN)

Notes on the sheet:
V1.0
Initial Release
2020/01/02
Vincent
50ohm Impedence
3.3V
300mA
1.2V
500mA
100mA
USB
868
915
SPI
For Power-up delay
V1.1
Add power up delay circuit at VCCIO
Add power up reset circuit for SX1302
Change pins refer to Semtech V3 Schematic
2021/02/18



Board: 4 copper layers, 30.0 x 51.0 mm, 244 parts (68 on the bottom side), 162 nets.

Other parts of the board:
U$45: SEEED-SILK-TNAME-280*268MIL

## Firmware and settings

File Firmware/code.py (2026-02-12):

print("Launching ModuPad, a custom macro pad built on KMK firmware for the - " \
" Seeed XIAO RP2040 microcontroller. Developed by M. Saim Ghazanfar.")

import board

from kmk.kmk_keyboard import KMKKeyboard
from kmk.keys import KC
from kmk.modules.macros import Macros
from kmk.modules.macros import Press, Release, Tap, Delay
from kmk.scanners import DiodeOrientation
from kmk.extensions.display import Display, TextEntry, ImageEntry
from kmk.modules.encoder import EncoderHandler
from kmk.extensions.media_keys import MediaKeys
from kmk.extensions.display.ssd1306 import SSD1306
import busio

#-----------------------------------------------------------------------------------

keyboard = KMKKeyboard()

# ==============================
#Switch setup
# ==============================s

keyboard.col_pins = (board.D0, board.D1, board.D2, board.D3)
keyboard.row_pins = (board.D8, board.D9, board.D10)
keyboard.diode_orientation = DiodeOrientation.COL2ROW

#Macro setup, you can define your macros here and then call them in the keymap. You can also define them directly in the keymap, but this way you can reuse them and keep the keymap cleaner.
macros = Macros()
KC.MACRO(
    on_press=None, 
    on_hold=None,
    on_release=None,
    blocking=True,
)
keyboard.extensions.append(macros)
OPEN_Youtube = KC.MACRO(
    Press(KC.LGUI),
    Tap(KC.R),
    Release(KC.LGUI),
    Delay(500), # Delay in milliseconds to allow the Run dialog to open, 500ms is equal to 0.5 seconds
    Tap(KC.W), # You can also use Tap(KC.HOME) or any other keycode to open a specific application or folder, but using the Run dialog is more versatile and works on all Windows versions.
    Tap(KC.ENTER)
)

Alt_Tab = KC.MACRO(
    Press(KC.LALT),
    Delay(30),
    Tap(KC.TAB),
    Delay(30),
    Release(KC.LALT),
)

keyboard.keymap = [
    [OPEN_Youtube, Alt_Tab, KC.N3, KC.N0,
    KC.N4, KC.N5, KC.N6, KC.NO,
    KC.N7, KC.N8, KC.N9, KC.NO],
]

#------------------------------------------------------------------------------------

encoder_handler = EncoderHandler()

# ==============================
# Encoder
# ==============================

# Regular GPIO Encoder Pins assigned as D-Pins, with no button and 2 steps per detent. 

encoder_handler.pins = ( (board.D6, board.D7, None, False, 2), ) 
keyboard.modules.append(encoder_handler)

# You can optionally predefine combo keys as for your layout, but you can also just use the encoder as a regular encoder and it will send the keycodes in the order defined in the map.

keyboard.extensions.append(MediaKeys())

# You can also use the encoder as a rotary switch by changing KC's To other Keycode, for exaample KC.A n B, and it will send the keycode on each step, Just like With Keyswitches.
encoder_handler.map = [ ((KC.AUDIO_VOL_UP, KC.AUDIO_VOL_DOWN, KC.NO),), # Standard
                        #((KC.VOLD, KC.VOLU, KC.NO),), # Extra
                        #((KC.A, KC.Z, KC.N1),), # NumPad not yet properly configured
                        #((KC.A, KC.Z, KC.N1),), # Gaming not yet properly configured

                        ]                      

#------------------------------------------------------------------------------------

# ==============================
#Display setup
# ==============================

# I2C setup
i2c = busio.I2C(board.SCL, board.SDA)

# Driver FIRST
driver = SSD1306(
    i2c=i2c,
    device_address=0x3C,
)

# Then Display

display = Display(
    display=driver,
    entries=[

        #TextEntry(text="Bilal ♥"#, x=0, y=0,#inverted=True, layer=0
        #   ),
        #TextEntry(text="Is't it Cool???? Huh?", x=0, y=16,#inverted=True, layer=0
        #          ),
        ImageEntry(image="3.bmp"#, x=0, y=0
                   ),    
        #ImageEntry(image="4.bmp", x=0, y=0),    

        ],

    width=128,
    height=32,
    flip = True, # flips your display content
    #flip_left = False, # flips your display content on left side split
    #flip_right = True, # flips your display content on right side split
    #brightness=0.8, # initial screen brightness level
    #brightness_step=0.1, # used for brightness increase/decrease keycodes
    dim_time=15, # time in seconds to reduce screen brightness
    dim_target=0.1, # set level for brightness decrease
    off_time=30, # time in seconds to turn off screen
    #powersave_dim_time=10, # time in seconds to reduce screen brightness
    #powersave_dim_target=0.1, # set level for brightness decrease
    #powersave_off_time=30, # time in seconds to turn off screen

)

keyboard.extensions.append(display)

#------------------------------------------------------------------------------------

if __name__ == '__main__':
    keyboard.go()

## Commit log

2025-12-26 Update and rename Universal Prompt for All Future Projects (Reusable Everywhere).md to Universal Project Documentation Prompt — Final .md File.md
2025-12-26 Update and rename ModuPad_Project_Report_v1_Learning_Focused_PROMPT.md to HackPad Project Prompt — Final .md File.md
2026-01-02 ModuPad folder structure
    [1_01 Table of Contents.kicad_sch, 2_02 Block Diagram.kicad_sch, 3_03 Power IN & MCU GPIOs.kicad_sch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]
2026-02-12 Implement macros and encoder functionality
    Added macro functionality for opening YouTube and Alt+Tabbing. Configured encoder handler and display settings.
2026-02-23 Clean up README by removing commented content
    Removed commented sections about device identity, encoder behavior, and firmware reasoning from the README.
2026-02-23 Add project journal entries and images
    Documented the status of the soldering iron, PCB, and 3D-printed case orders. Added images related to the project.
2026-02-23 Add firmware rewriting process
    Documented the process of rewriting firmware for the Seeed XIAO RP2040, including testing the encoder functionality and confirming no hardware issues.
2026-02-23 Shifted TO QMK
    Documented testing and implementation efforts for encoder and QMK firmware.
2026-02-23 Add ModuPad Journal 06 detailing case assembly issues
    Documented the delivery and assembly issues encountered with the ModuPad case, including measurement errors and necessary modifications.
2026-02-23 Key Testings
    Document progress on key switch testing and issues encountered.
2026-02-23 Updated README
    Added a Bill of Materials section to the README.
